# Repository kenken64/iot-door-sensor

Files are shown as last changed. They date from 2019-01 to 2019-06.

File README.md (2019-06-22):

# Door/Window Sensor - Internet of Things

## Tindie Store - Order the device here https://bit.ly/2L2vBSy 

### If you would like to see further enhancement of this whole iot platform kindly donate to my BTC account

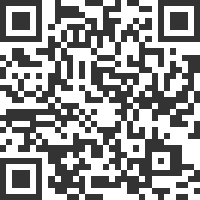
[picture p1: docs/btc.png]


IMAGE ALT TEXT HERE (https://www.youtube.com/watch?v=pYRvByaGBP0)

IMAGE ALT TEXT HERE (https://youtu.be/cuYwMgwrSvQ)

Nothing spells security than being notified or alerted if somebody has entered your premises without your permission. It also helps when even before someone can gain entry, you already know who he or she is. The main idea of this door/window sensor is to simply provide you information if someone has gone through any of your property entry points.

## Works with Many Entry Points

The door/window sensor is primarily used to detect people or objects that have passed through the doors, but it’s also compatible to windows and any enclosures that could be opened.

## Small to Notice

The door/window sensor is a very unassuming device so it blends well with the rest of the commonly found items or appliances in your home. It is also quite small you can easily hide it well, away from the prying eyes of potential intruders, and it doesn’t get in the way with the actual functions of the entry points.

The device is a magnetic switch that allows it to accurately determine location and direction. In other words, there are no false alarms and leads.

## Very Easy and Fast Installation

As a magnetic device, it doesn’t require any intricate tools to install. In fact, you simply need to snap it into any metal part of your entryway, and you can already properly and quickly configure the door sensor. If not, you can conveniently attached even a small piece of metal at any part of the door and window.

## Works on the cloud

A connected home brings devices and services together for an integrated, autonomous experience that improves a consumer’s life. Connected home experiences include everything from window/door sensor , voice-controlled lights, house-cleaning robots, machine learning-enabled security cameras, and WiFi routers that troubleshoot for you. Thanks to decreasing costs and increasing options for connectivity, these smart home devices, sensors, and tools can be interlinked to create real-time, contextual, and smart experiences for consumers.

IoT powers the connected home by bringing new features and capabilities to smart devices, like interconnectivity, security, offline communication, predictive maintenance, analytics for consumer insights, and machine learning. Each of these capabilities play a different role in key connected home use cases such as home automation, home security and monitoring, and home networking.

# Multiple version
- Wifi version
- Sigfox version
- Lorawan version require an existing lorawan gateway (Prototype, too expensive)

# Pre-requisite Lora Gateway
- Use the raspi-config tool (with sudo raspi-config) to enable SPI on the Raspberry Pi
- Install wiringpi (sudo apt-get install wiringpi)

# Pre-requisite microcontroller and parts
- Adafruit Huzzah ESP8266/TTGO ESP32 Wifi/Arduino UNO
- 2-way connector
- LED
- 47k Ohm Resistor
- 10k Ohm Resistor
- 220 Ohm Resistor
- Magnetic Door Sensor
- Jumper
- Custom made PCB by kenken64
- Lipo Battery/ 18650 battery
- Headers 
- UnaShield Sigfox for Arduino UNO

## 3D printed Casing/Housing
- ESP8266/ESP32 STL 3d Design
- Sigfox STL 3d Design

# PCB Design (Eagle and Fritzing)
- WIFI Version 1 (Custom made PCB)
<br>
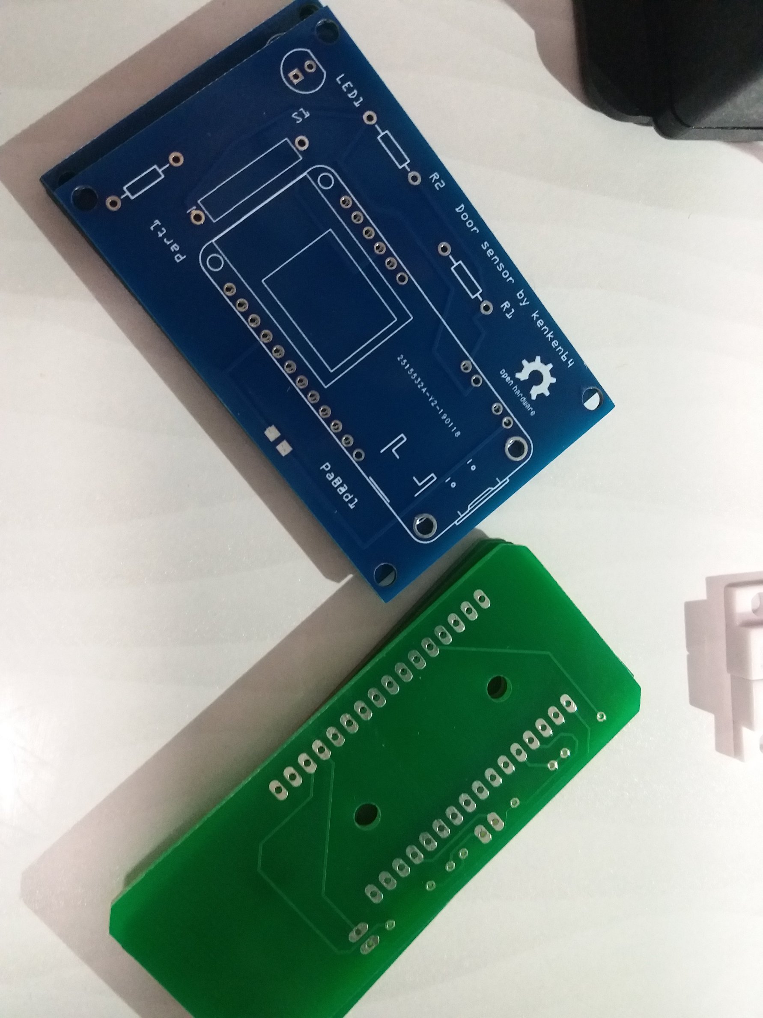
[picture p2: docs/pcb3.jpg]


- WIFI Version 2 (Custom made PCB)
<br>
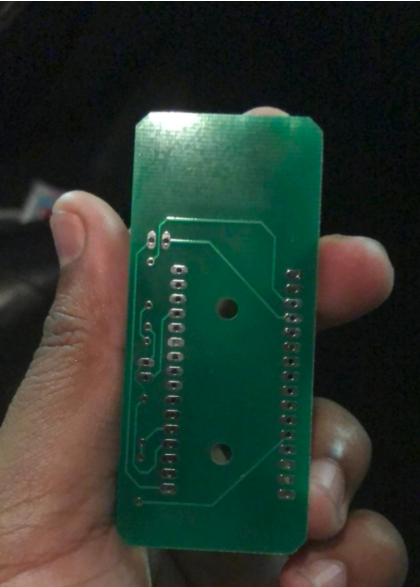
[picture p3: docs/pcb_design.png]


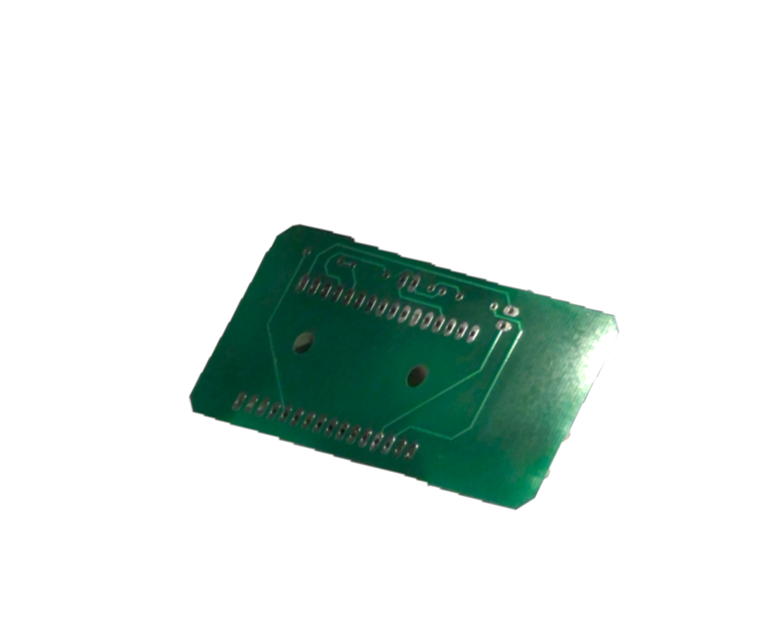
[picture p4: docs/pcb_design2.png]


- Sigfox version (Shield from UnaBiz)

# Pre-requisite software & library

- Microsoft Visual Studio Code
- Node JS
- Ubuntu/Windows 10 ( 2 CPU and 2GB ram )
- Angular 7 Cli
- Arduino IDE
- ESPBattery
- ESP 8266/32 Arduino library
- Unashield Sigfox library

# Pre-requisite Cloud account

- Twilio (require your own credit to send out SMS/WhatsApp)
- Gmail https://mail.google.com/mail/u/0/
- Google Firebase Realtime Database https://console.firebase.google.com/u/0/?pli=1
- Blynk Cloud Service ( Mobile App) 

# Twilio - SMS and WhatsApp Notification

- Create a twilio account and top up with the credits.
- Note down the twilio SSID and AUTH TOKEN.
- Purchase a number from Twilio
- Also note down the WhatsApp from number

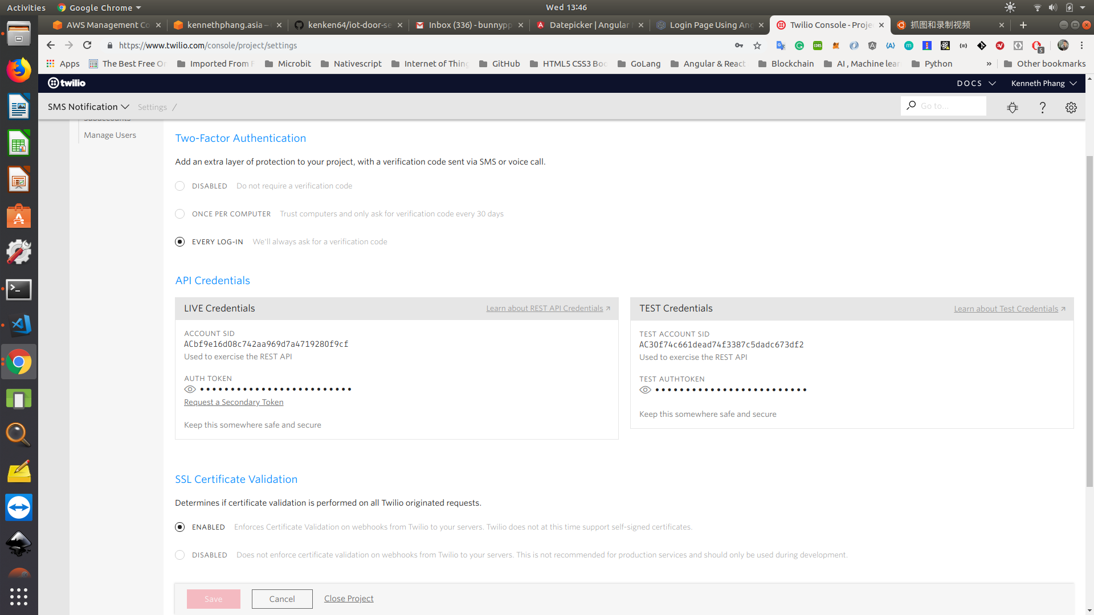
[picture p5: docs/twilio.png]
Image of Twilio


# SMTP or Gmail account Email notification

- Create gmail account. Please do not use personal gmail account for this.
- Enable unsecure access to this account [Gmail API setting](https://support.google.com/accounts/answer/6010255?hl=en)

# Backend Server Side (AWS Lightsail/ DO / Azure / Google Cloud)
- Detect door is open and closed.
- Send SMS using twilio to the configure recipient mobile number
- Send notification email to the configure recipient email address
- Detect battery is low send notification via SMS and email
- Log all events to the door's device
- Provide exportable reporting of all doors 

# Environment variable

| Env variables | Description | 
| --- |:---:|
| SMTP_GMAIL_ACC | Gmail SMTP account that use to send email to security guard  | 
| SMTP_GMAIL_PASSWORD | Password for the above email account |  
| TWILIO_SSID | SSID for the twilio sms APIs | 
| TWILIO_AUTH_TOKEN | Security token for the twilio sms APIs | 
| TWILIO_NUMBER | You need a twilio phone number in order to send SMS to the receipient | 
| FIREBASE_DB_URL | NoSQL Database url | 
| JOB_INTERVAL | Interval period where the job poll for the changes from firebase and the blynk APIs | 
| JOB_TIMEOUT | Tiemout period where the job poll for the changes from firebase and the blynk APIs | 
| NOTIFICATION_ENABLE | Disable and enable notification when door is open and closed | 
| FIREBASE_SVC_ACC_FILE | Firebase credential file to perform admin operations e.g.  https://door-sensor-proj.firebaseio.com  | 
| CLEAN_UP_SCHEDULE | Schedule timing to cleanup events logs | 
| BLYNK_API_URL | Blynk IOT API URL  e.g. http://blynk-cloud.com/ | 
| SIGFOX_SERVER_PORT | Sigfox callback backend server port number |
| TWILIO_WHATSAPP_NO | Twilio WhatsApp from number |

# Door/Window sensor Web App

## List of door/window installed with sensor

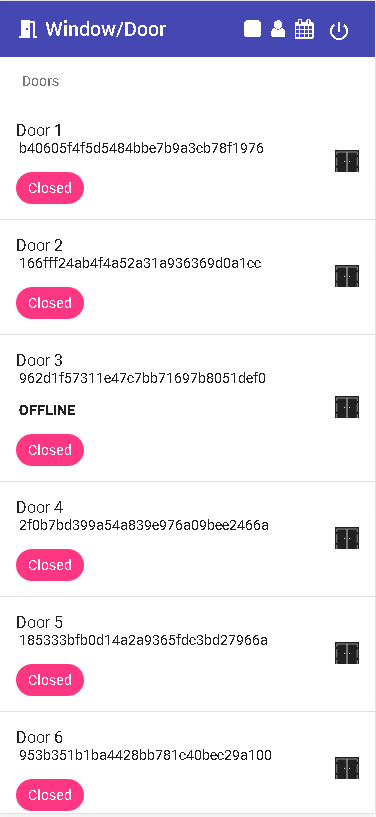
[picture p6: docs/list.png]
List of doors


## Add new door/window sensor
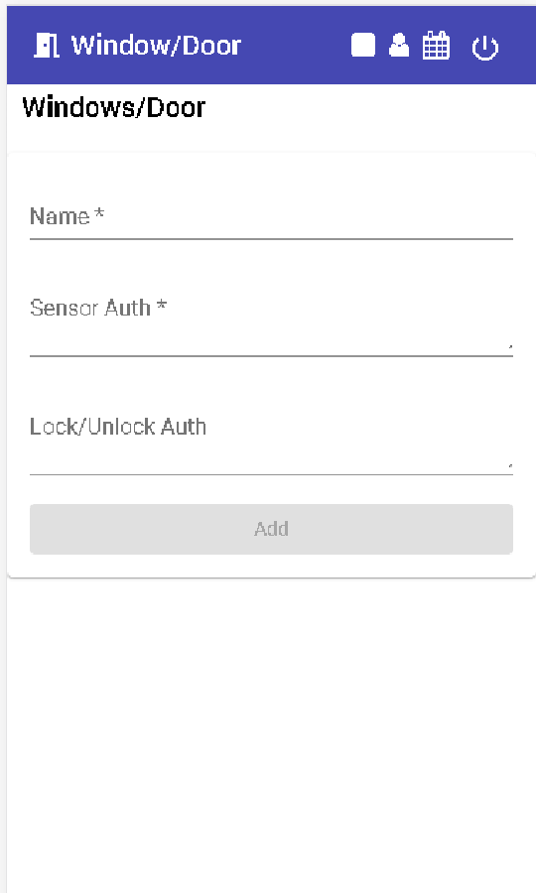
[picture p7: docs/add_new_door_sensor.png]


## Add new security personel to the system
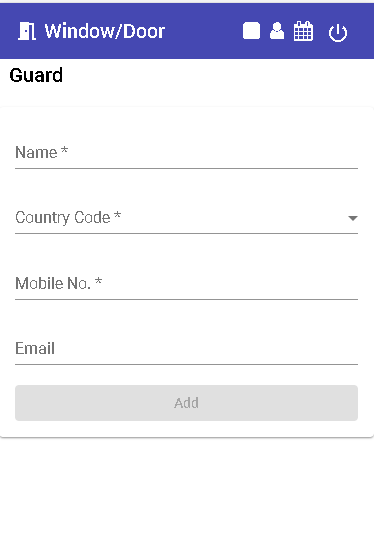
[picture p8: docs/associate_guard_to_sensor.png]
Add guard to the system


## Associate multiple security guard to the sensors
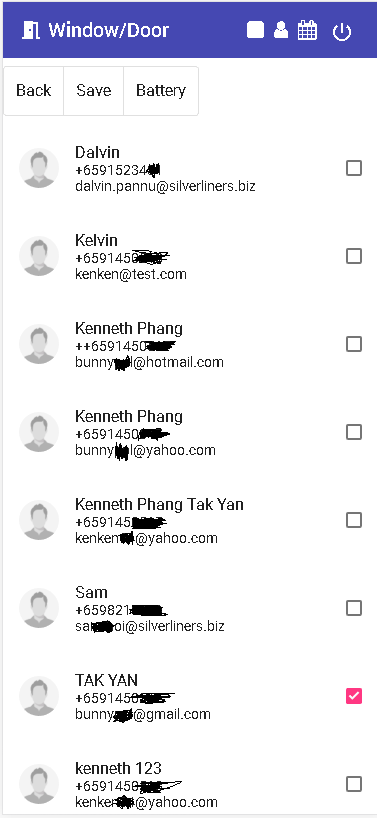
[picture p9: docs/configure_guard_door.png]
Associate guard to the door sensors


## Provide feedback on door/window events
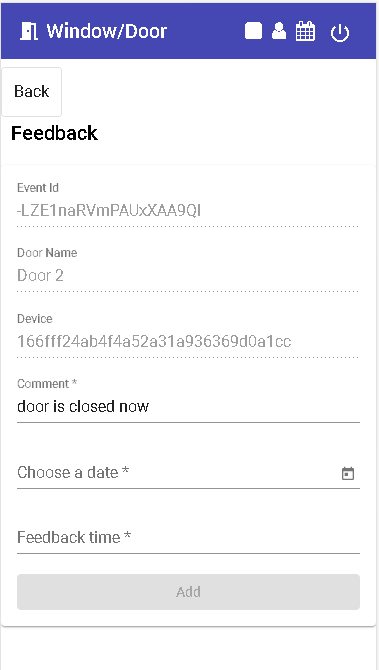
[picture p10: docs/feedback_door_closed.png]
feedback on events


## SMS Notification
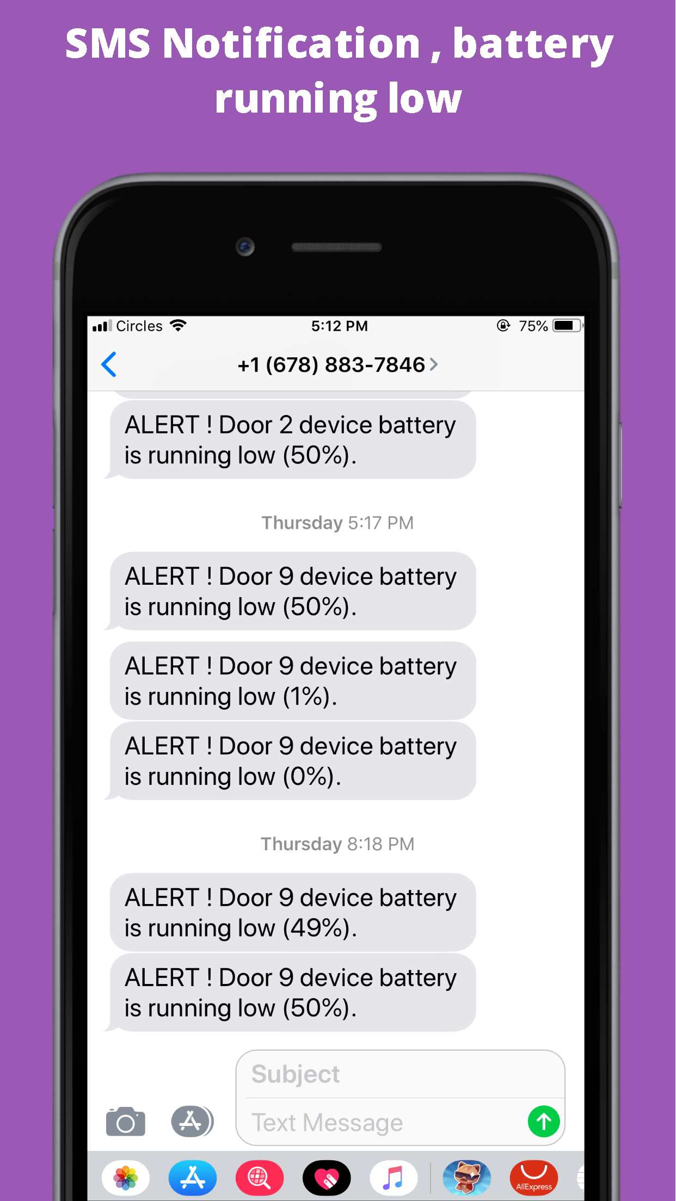
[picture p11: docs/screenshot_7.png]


## Email Notification
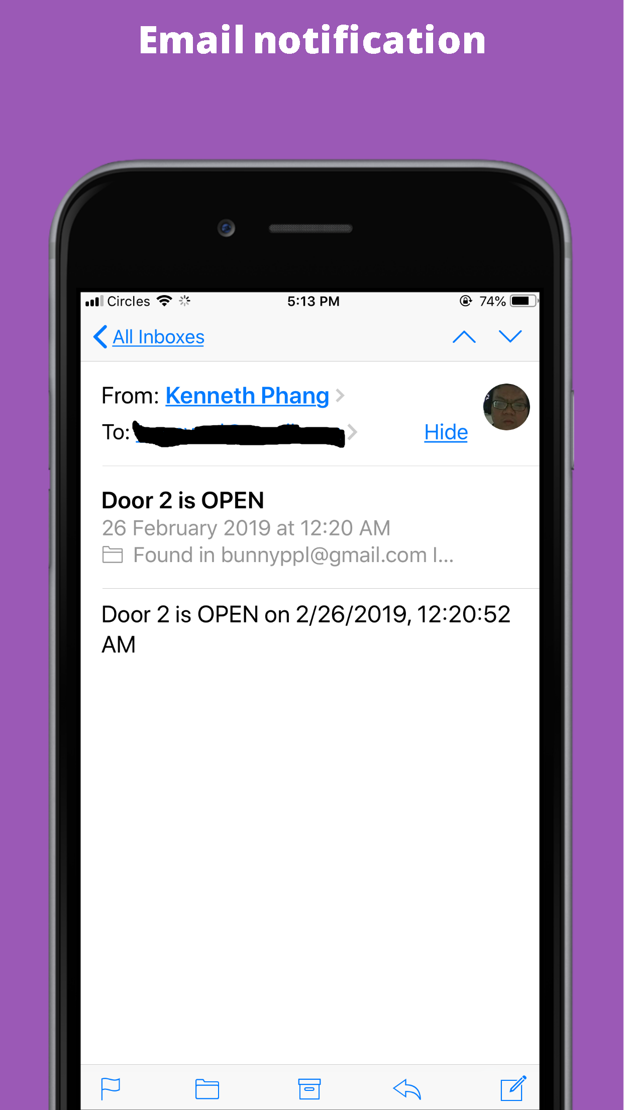
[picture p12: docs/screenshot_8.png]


## WhatsApp Notification
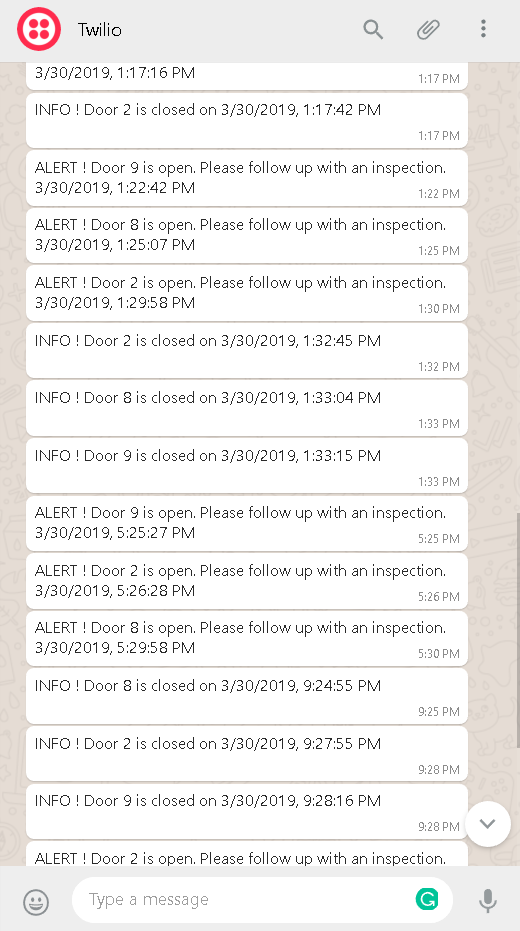
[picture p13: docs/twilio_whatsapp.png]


## Export as Excel Spreadsheet
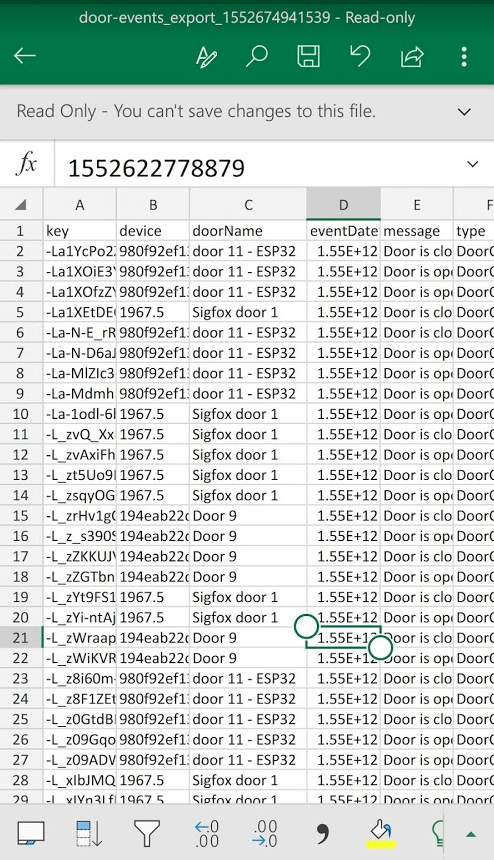
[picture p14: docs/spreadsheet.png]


# Setup Instructions for the PWA Web App and Backend

Kindly create a Azure/AWS/Google Cloud account to deploy all this component on a Ubuntu 18.04 distribution

After creating a cloud instance, ssh/login into the instance install git software and node js. Please follow the links below with all the installation steps 

https://www.digitalocean.com/community/tutorials/how-to-install-git-on-ubuntu-18-04-quickstart

https://www.digitalocean.com/community/tutorials/how-to-install-node-js-on-ubuntu-18-04

This project was generated with [Angular CLI](https://github.com/angular/angular-cli) version 7.1.4.

## Logon to the newly created cloud server and pull down the github source codes using the below linux command

```
cd ~
git clone https://github.com/kenken64/iot-door-sensor.git
```
## Development server

Run `ng serve` for a dev server. Navigate to `http://localhost:4200/`. The app will automatically reload if you change any of the source files.

## Code scaffolding

Run `ng generate component component-name` to generate a new component. You can also use `ng generate directive|pipe|service|class|guard|interface|enum|module`.

## Build

Run `ng build` to build the project. The build artifacts will be stored in the `dist/` directory. Use the `--prod` flag for a production build.

## Running unit tests

Run `ng test` to execute the unit tests via [Karma](https://karma-runner.github.io).

## Running end-to-end tests

Run `ng e2e` to execute the end-to-end tests via [Protractor](http://www.protractortest.org/).

## Further help

To get more help on the Angular CLI use `ng help` or go check out the [Angular CLI README](https://github.com/angular/angular-cli/blob/master/README.md).

## Install PWA from dist directory to Nginx 

Use the link below for the nginx installation

https://www.digitalocean.com/community/tutorials/how-to-install-nginx-on-ubuntu-18-04

Right after the web server is installed, install free SSL certificate using Let's Encrypt 

https://www.digitalocean.com/community/tutorials/how-to-secure-nginx-with-let-s-encrypt-on-ubuntu-18-04

Lastly, copy all the files from the angular app /dist directory to the nginx web server root directory e.g. /var/www/html

## Google Firebase

It is must to have Google account in order to create a firebase account for this project

1. Create a firebase real time database project following this link https://firebase.google.com/

## Install and start redis server

1. Install redis server

```
sudo apt-get update
sudo apt-get install redis
```

2. Start Redis server

```
sudo service redis-server start
```
3. Check redis server status
```
sudo service redis-server status
```

4. if only there is a crash on the worker process then run flush

```
redis-cli FLUSHALL
```

## Start Backend server
How to start the sms and email backend server that poll the devices.

```
$ cd server/
$ npm i 
$ pm2 start server.js --name server --max-memory-restart 1G --restart-delay 10000 --node-args="--expose-gc --max-old-space-size=4096"
```

## Start Door Sensor Worker Engine to poll door's state
Worker consumes the job from the delegator to check the door sensors and send out notification via SMS/WhatsApp/Email.

Each worker is configured with its own designated door sensor's blynk auth key. Refer to the server/worker-config.json

```
[
    {
        "workerName": "worker1",
        "doors": ["b40605f4f5d5484bbe7b9a3cb78f1376",
                "962d1f57311e47c7bb71697b8051de30",
                "980f92ef13db430594a89315d86dd37b"

        ]
    },
    {
        "workerName": "worker2",
        "doors": [ "185333bfb0d14a2a9365fdc3bd37966a",
                "953b351b1ba4428bb781c40bec29a300",
                "194eab22d2bd49c0a580c01d7d19ce34"
        ]
    },
    {
        "workerName": "worker3",
        "doors": [ "166fff24ab4f4a52a31a936369d3a1cc",
                "2dde80b00cf342c1b6977e91dd9b6039"
        ]
    },
    {
        "workerName": "worker4",
        "doors": [ "c56c9a1ab4b1415998c06173786354f2",
                "2f0b7bd399a54a839e976a09bee2463a"
        ]
    }
]
```

```
$ cd server/
$ pm2 start worker.js --name worker --max-memory-restart 500M -- --workername=worker1 --node-args="--expose-gc
$ pm2 start worker.js --name worker2 --max-memory-restart 500M -- --workername=worker2 --node-args="--expose-gc
$ pm2 start worker.js --name worker3 --max-memory-restart 500M -- --workername=worker3 --node-args="--expose-gc
$ pm2 start worker.js --name worker4 --max-memory-restart 500M -- --workername=worker4 --node-args="--expose-gc
```

## Blynk Configuration

Go to your Google App Store/Apple store search for Blynk, install it

Register an account with Blynk

Create a new project, choose device as ESP8266 WIFI send the auth key to your email address

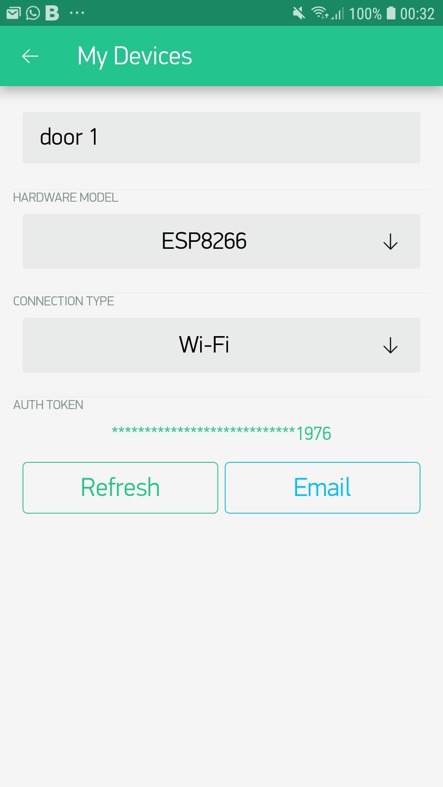
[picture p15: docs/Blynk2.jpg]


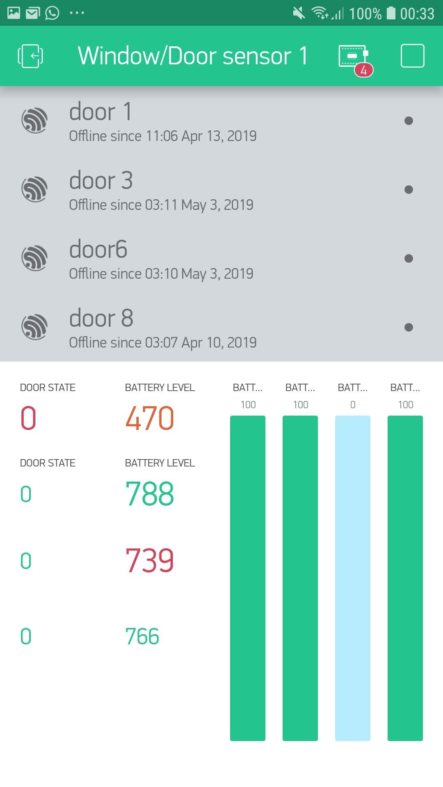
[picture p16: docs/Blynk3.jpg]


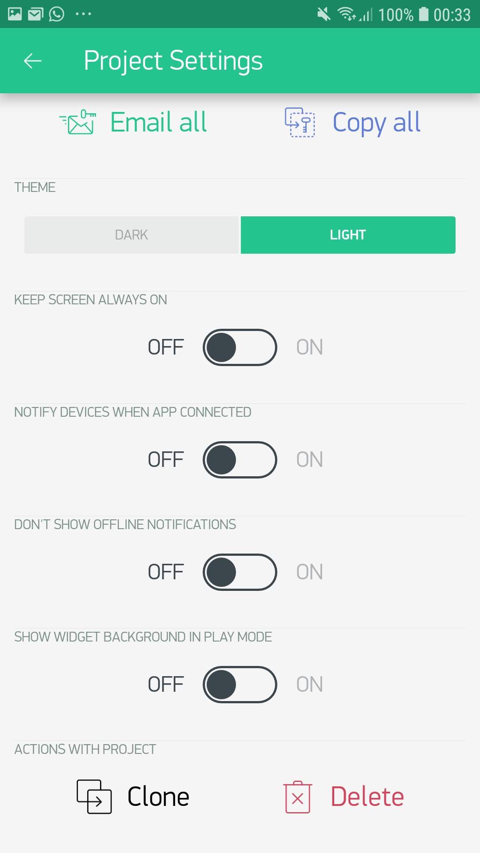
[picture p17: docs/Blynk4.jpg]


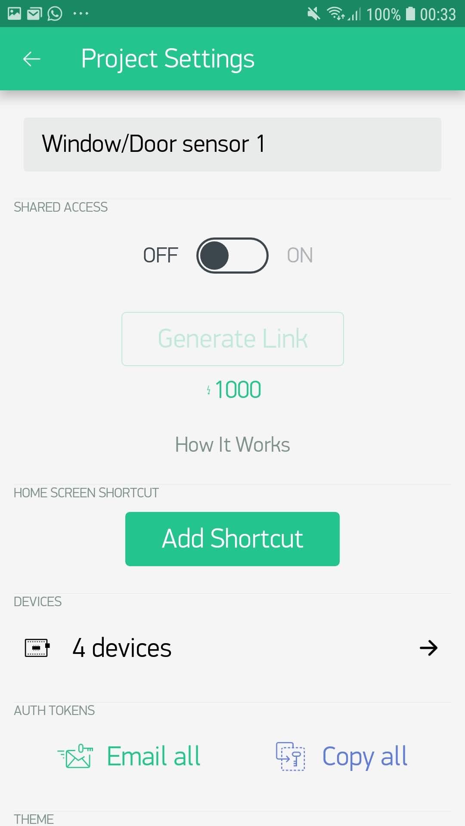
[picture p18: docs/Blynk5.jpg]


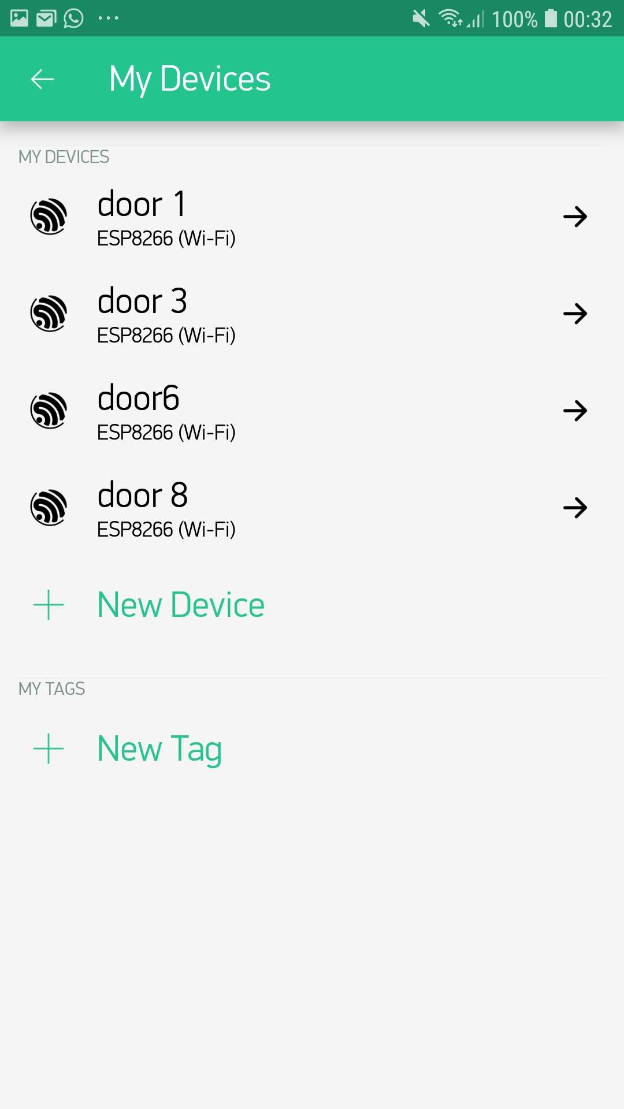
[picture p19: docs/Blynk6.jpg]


## Restful API for Blynk

Below is the link to test out the API using your REST client
https://blynkapi.docs.apiary.io/#

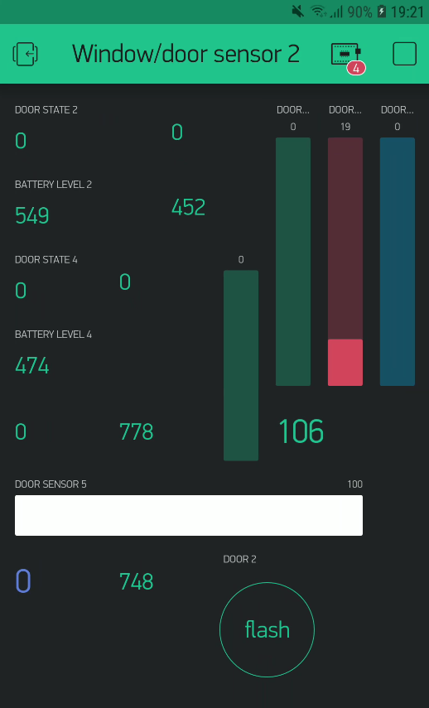
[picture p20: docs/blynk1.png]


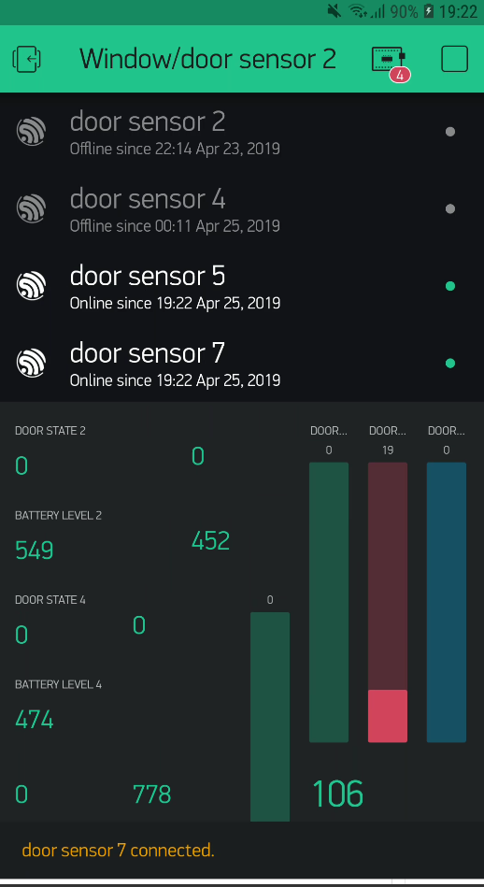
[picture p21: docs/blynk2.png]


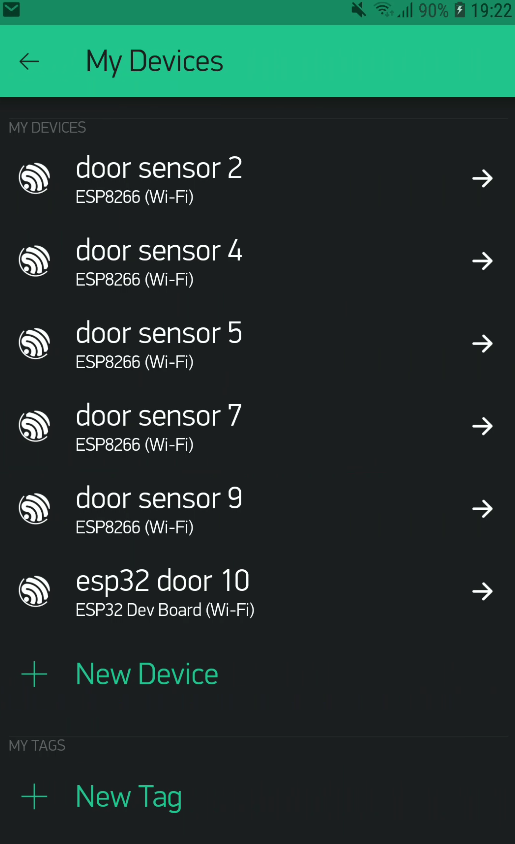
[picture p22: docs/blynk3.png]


## Install firmware to the ESP8266/ESP32

1. Plug the ESP8266 to your computer
2. Launch Arduino IDE , open up the Arduino sketch from the directory /firmware/door_sensor/door_sensor.ino
3. Search for the codes, replace the double quote values according to the auth code from the blynk email from your mailbox
```
char blynk_token[33] = "166fff24ab4f4a52a31a936369d0a1cc";
```
4. Make sure ESP8266 board are installed using the board manager.

arduino board

5. Select the configuration properly before compiling and flashing the ESP8266. Take note the flash size and port.

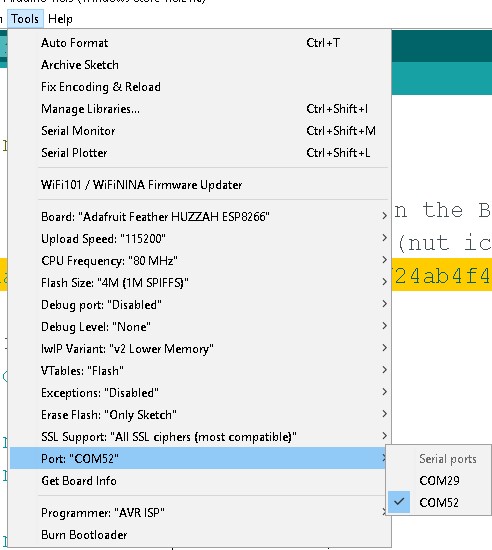
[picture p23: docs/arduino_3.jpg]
config


5. The following libraries is amust to be installed before sync the firmware to the ESP8266 board
  - ArduinoJson (Take note do not use the latest version)
  arduino Json

  - FS
  SPI Flash
  unified sensor

  - ESPBattery (https://github.com/LennartHennigs/ESPBattery)
  - Blynk
  blynk

  - WifiManager
  wifimanager  

6. Compile and sync the firmware to the microcontroller board

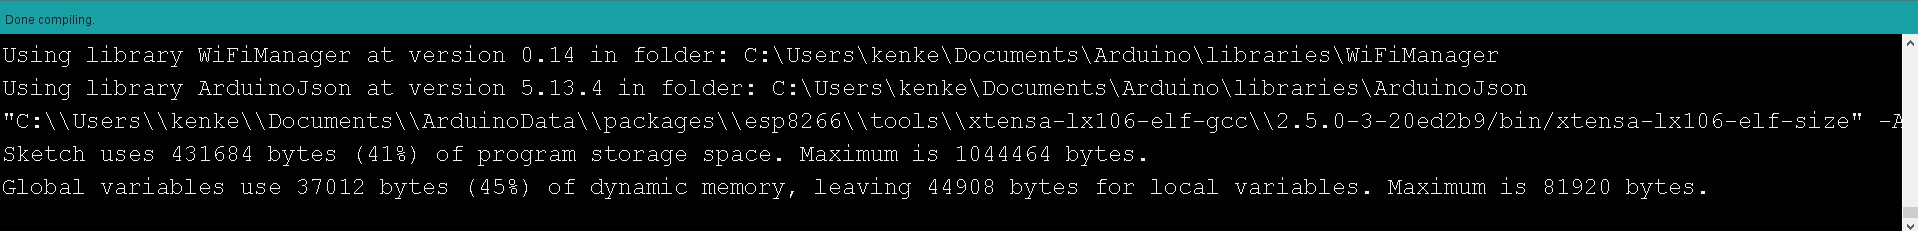
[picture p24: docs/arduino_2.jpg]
compile sync


## Once everything is setup and up running on the cloud

Last thing to do is to power up the door sensor using a micro usb cable, at first if there isn't any wifi setting being configure. the device  will act as an wireless access point with the SSID stated as "AutoAPDoorSensor" Access the portal via the following web address htttp://192.168.244.1

Configure the door sensor device to connect to your own wifi router with credential. Do not change the blynk auth key.

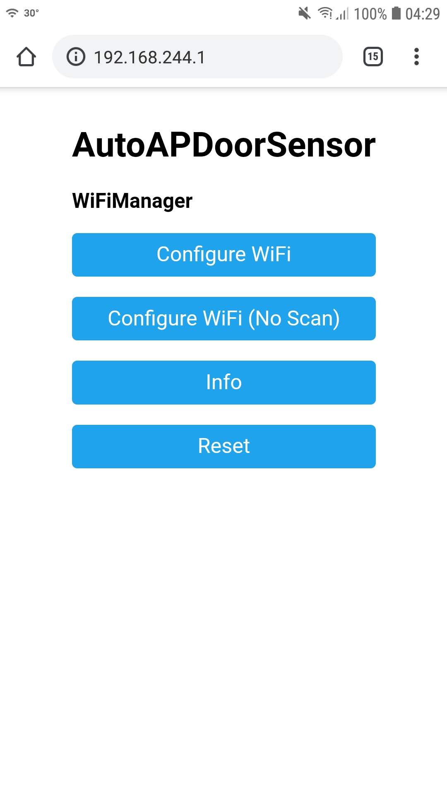
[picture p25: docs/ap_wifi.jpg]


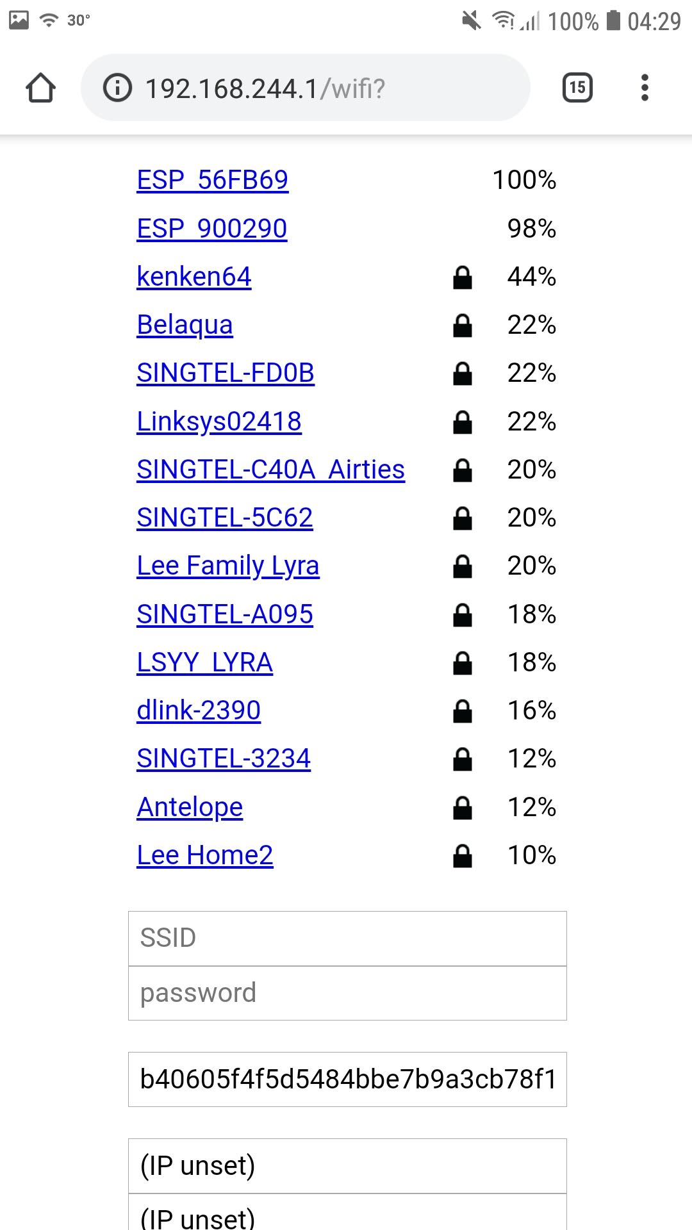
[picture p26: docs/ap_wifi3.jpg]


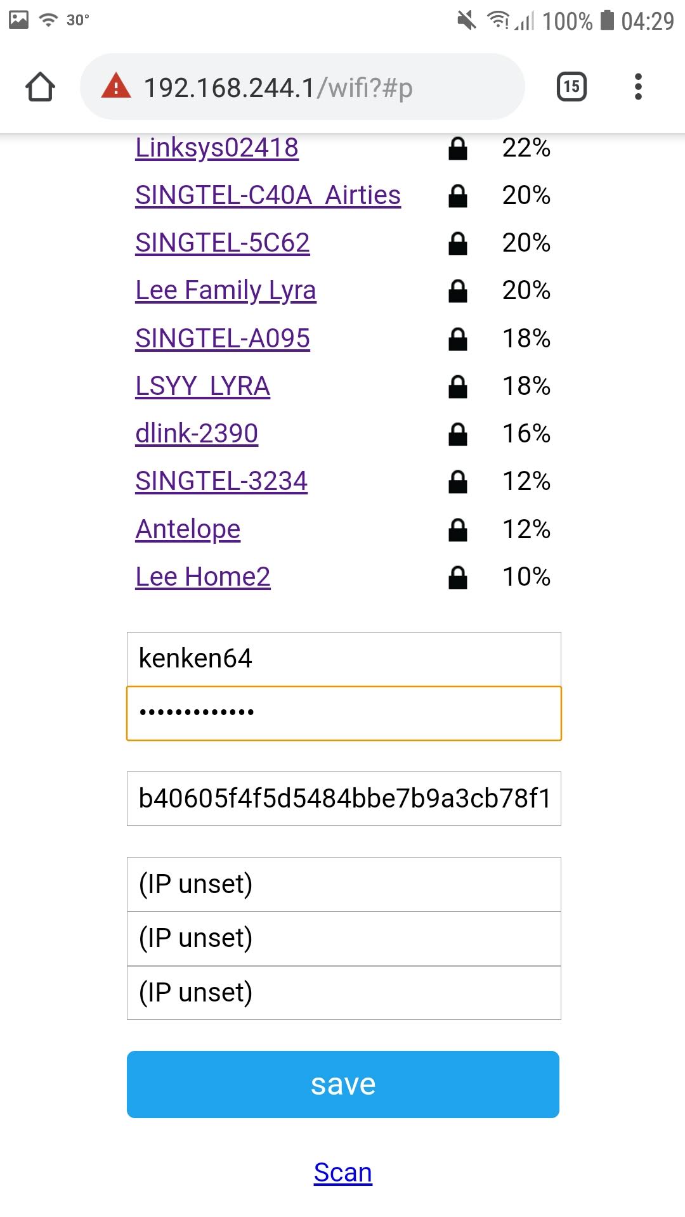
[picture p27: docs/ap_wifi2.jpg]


## Check the health of all processes
```
pm2 list
```
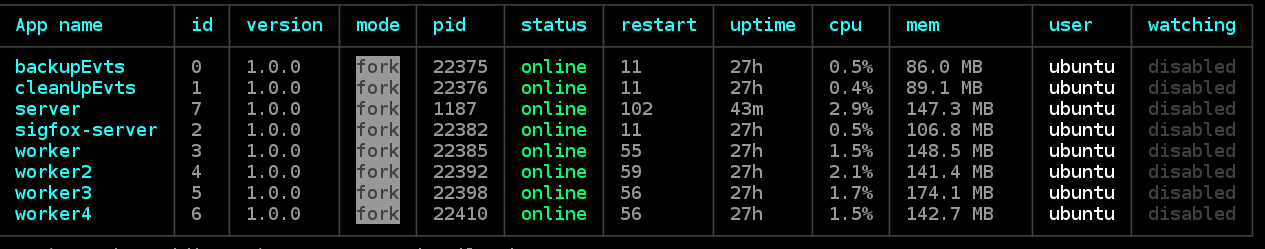
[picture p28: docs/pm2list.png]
pm2 list


## Debug memory leakage
- Use ChromeDev Tools
- Dynatrace (https://www.dynatrace.com/)
- Sentry io (https://sentry.io/welcome/)

## Future work - Integrate with ElectricMagnetic lock 

Most of the EM lock in the market uses 12v AC likely need to enhance the PCB board

https://shopee.sg/Hot-DC-DC-Converter-Output-Power-Adapter-24V-12V-To-5V-USB-Step-Down-Module-i.10885840.691201434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

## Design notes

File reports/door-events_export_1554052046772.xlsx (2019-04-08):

key | device | doorName | eventDatetime | message | type | feedbackcnt
-LbJhYLAxj5AkwDbXFJq | 980f92ef13db430594a89315d86dd77b | door 11 - ESP32 | 1554051904958 | Door is open | DoorOpen
-LbG9qbOESUnvReJJRC1 | 166fff24ab4f4a52a31a936369d0a1cc | Door 2 | 1553992477195 | Door is closed | DoorClosed
-LbG9p6t_31eekwN8Nhz | 166fff24ab4f4a52a31a936369d0a1cc | Door 2 | 1553992471083 | Door is open | DoorOpen
-LbF4HRLtCv06RyEZqPL | 980f92ef13db430594a89315d86dd77b | door 11 - ESP32 | 1553974241097 | Door is closed | DoorClosed
-LbF4BapXU5PSPsuM1WS | 980f92ef13db430594a89315d86dd77b | door 11 - ESP32 | 1553974217192 | Door is open | DoorOpen
-LbF23VppiVC7AHFCAK1 | 980f92ef13db430594a89315d86dd77b | door 11 - ESP32 | 1553973659752 | Door is closed | DoorClosed
-LbF1b_nuyKv48idWVYl | 980f92ef13db430594a89315d86dd77b | door 11 - ESP32 | 1553973541286 | Door is open | DoorOpen
-LbEzBxsZmUcK-HE3RZI | 980f92ef13db430594a89315d86dd77b | door 11 - ESP32 | 1553972645803 | Door is closed | DoorClosed
-LbEyXHlW8qjmYxzAT_T | 980f92ef13db430594a89315d86dd77b | door 11 - ESP32 | 1553972471012 | Door is open | DoorOpen
-LbEYIYzXVmZFBGb-Gbn | 166fff24ab4f4a52a31a936369d0a1cc | Door 2 | 1553965332785 | Door is closed | DoorClosed
-LbEYH3oPG80vjXWrKoD | 166fff24ab4f4a52a31a936369d0a1cc | Door 2 | 1553965326694 | Door is open | DoorOpen
-LbE0enKn01YblO7EN7C | 166fff24ab4f4a52a31a936369d0a1cc | Door 2 | 1553956515079 | Door is closed | DoorClosed
-LbE09NuWr0WJ_i1VxAT | 166fff24ab4f4a52a31a936369d0a1cc | Door 2 | 1553956382316 | Door is open | DoorOpen
-LbDvbwL5F5xs5sZkF97 | 166fff24ab4f4a52a31a936369d0a1cc | Door 2 | 1553954934039 | Door is closed | DoorClosed
-LbDvEdwf5Irp-qYl86a | 166fff24ab4f4a52a31a936369d0a1cc | Door 2 | 1553954834557 | Door is open | DoorOpen
-LbDmJpFzunIPoxMLrfH | 194eab22d2bd49c0a580c01d7d19ce44 | Door 9 | 1553952496420 | Door is closed | DoorClosed
-LbDmEh007m0BIL5UEbW | 166fff24ab4f4a52a31a936369d0a1cc | Door 2 | 1553952475412 | Door is closed | DoorClosed
-LbDlYqbU7AalJLbQc5t | c56c9a1ab4b1415998c06173786454f2 | Door 8 | 1553952295506 | Door is closed | DoorClosed
-LbCvm6ujX3tMpaGg5Z9 | c56c9a1ab4b1415998c06173786454f2 | Door 8 | 1553938198181 | Door is open | DoorOpen
-LbCuynzfubFud5L3ltw | 166fff24ab4f4a52a31a936369d0a1cc | Door 2 | 1553937988012 | Door is open | DoorOpen
-LbCujvWsiUAAoS5gcs- | 194eab22d2bd49c0a580c01d7d19ce44 | Door 9 | 1553937927060 | Door is open | DoorOpen
-LbC4aiUu0B3rXRMKoM2 | 194eab22d2bd49c0a580c01d7d19ce44 | Door 9 | 1553923995449 | Door is closed | DoorClosed
-LbC4Z3IujFd2DL-WBQU | c56c9a1ab4b1415998c06173786454f2 | Door 8 | 1553923984554 | Door is closed | DoorClosed
-LbC4UOF-QtK1Jrwupyu | 166fff24ab4f4a52a31a936369d0a1cc | Door 2 | 1553923965417 | Door is closed | DoorClosed
-LbC3qTX1ZaQKLYrBip8 | 166fff24ab4f4a52a31a936369d0a1cc | Door 2 | 1553923797819 | Door is open | DoorOpen
-LbC2jSPwQlkLe3CMb9D | c56c9a1ab4b1415998c06173786454f2 | Door 8 | 1553923506903 | Door is open | DoorOpen
-LbC2B6hIbkSxb11lPas | 194eab22d2bd49c0a580c01d7d19ce44 | Door 9 | 1553923362158 | Door is open | DoorOpen
-LbC11kzToeCQnQw2DZF | 166fff24ab4f4a52a31a936369d0a1cc | Door 2 | 1553923061692 | Door is closed | DoorClosed
-LbC0wTUq6ODVgqIYA8s | 166fff24ab4f4a52a31a936369d0a1cc | Door 2 | 1553923035932 | Door is open | DoorOpen
-LbBzAV1fcKUq9rwFM6O | 166fff24ab4f4a52a31a936369d0a1cc | Door 2 | 1553922311037 | Door is closed | DoorClosed
-LbByqNt5y6tALvIQPkJ | 166fff24ab4f4a52a31a936369d0a1cc | Door 2 | 1553922224563 | Door is open | DoorOpen
-LbBtDIWIDM1xUbAMDD7 | 166fff24ab4f4a52a31a936369d0a1cc | Door 2 | 1553920749635 | Door is closed | DoorClosed
-LbBtArpjILaWVlY_XfR | 166fff24ab4f4a52a31a936369d0a1cc | Door 2 | 1553920739671 | Door is open | DoorOpen
-LbBsxxXh0H3BcSDuWva | 166fff24ab4f4a52a31a936369d0a1cc | Door 2 | 1553920682691 | Door is open | DoorOpen
-LbBrqf8_DRZe51GHhWX | 166fff24ab4f4a52a31a936369d0a1cc | Door 2 | 1553920390687 | Door is closed | DoorClosed
-LbBegRynJfydQi0RYww | 166fff24ab4f4a52a31a936369d0a1cc | Door 2 | 1553916940864 | Door is open | DoorOpen
-Lb9k7stFvZPYi2gk4Pf | 166fff24ab4f4a52a31a936369d0a1cc | Door 2 | 1553884812999 | Door is closed | DoorClosed
-Lb9k1c3uTLVlwtuJR8N | 166fff24ab4f4a52a31a936369d0a1cc | Door 2 | 1553884787345 | Door is open | DoorOpen
-Lb9j6nhOxlyQLvP2czE | 166fff24ab4f4a52a31a936369d0a1cc | Door 2 | 1553884546426 | Door is closed | DoorClosed
-Lb9hn9R4HJCV5dAaVVz | 166fff24ab4f4a52a31a936369d0a1cc | Door 2 | 1553884199707 | Door is open | DoorOpen
-Lb9edZbjP7qyD6bmQh0 | c56c9a1ab4b1415998c06173786454f2 | Door 8 | 1553883373976 | Door is closed | DoorClosed
-Lb9eY9HkcYBfAvVf3zs | 166fff24ab4f4a52a31a936369d0a1cc | Door 2 | 1553883347715 | Door is closed | DoorClosed
-Lb9eMJlBwC80lkaq-zD | c56c9a1ab4b1415998c06173786454f2 | Door 8 | 1553883299234 | Door is open | DoorOpen
-Lb9eIQ76gKDyR0SeKzT | 166fff24ab4f4a52a31a936369d0a1cc | Door 2 | 1553883283257 | Door is open | DoorOpen
-Lb9dp20wL56oBHWFrNz | c56c9a1ab4b1415998c06173786454f2 | Door 8 | 1553883158829 | Door is closed | DoorClosed
-Lb9dmh4nlIv8YqJVWht | 166fff24ab4f4a52a31a936369d0a1cc | Door 2 | 1553883149233 | Door is closed | DoorClosed
-Lb9d_Nr9EYzGYrdl9br | c56c9a1ab4b1415998c06173786454f2 | Door 8 | 1553883094691 | Door is open | DoorOpen
-Lb9dWLVsx4SWk-F23mn | 166fff24ab4f4a52a31a936369d0a1cc | Door 2 | 1553883078156 | Door is open | DoorOpen
-Lb9cFwzByTY4B0ZGAHY | c56c9a1ab4b1415998c06173786454f2 | Door 8 | 1553882748835 | Door is closed | DoorClosed
-Lb9c9VB86PR5dCSGYc4 | c56c9a1ab4b1415998c06173786454f2 | Door 8 | 1553882722415 | Door is open | DoorOpen
-Lb9c4c2KMrISi6HIs_q | c56c9a1ab4b1415998c06173786454f2 | Door 8 | 1553882702438 | Door is closed | DoorClosed
-Lb9c4KUGgBpqNgY1JDO | 166fff24ab4f4a52a31a936369d0a1cc | Door 2 | 1553882701251 | Door is closed | DoorClosed
-Lb9bZ4yb63dhlHDQgF_ | c56c9a1ab4b1415998c06173786454f2 | Door 8 | 1553882565086 | Door is open | DoorOpen
-Lb9bWJUX8R_CxoQRujq | 166fff24ab4f4a52a31a936369d0a1cc | Door 2 | 1553882553727 | Door is open | DoorOpen
-Lb9aKTpNrMY7oEfL8mn | c56c9a1ab4b1415998c06173786454f2 | Door 8 | 1553882243087 | Door is closed | DoorClosed
-Lb9_kXTOi8WEEcKdIIR | c56c9a1ab4b1415998c06173786454f2 | Door 8 | 1553882091773 | Door is open | DoorOpen
-Lb9XzEwL5kBM-QHX5dT | 166fff24ab4f4a52a31a936369d0a1cc | Door 2 | 1553881365573 | Door is closed | DoorClosed
-Lb9Xq1dkC67nP3ZX9TD | 166fff24ab4f4a52a31a936369d0a1cc | Door 2 | 1553881327858 | Door is open | DoorOpen
-Lb9WKILswfy7ph2xQLP | 166fff24ab4f4a52a31a936369d0a1cc | Door 2 | 1553880931607 | Door is closed | DoorClosed
-Lb9Vp_LVu_RtAfHo_MM | 166fff24ab4f4a52a31a936369d0a1cc | Door 2 | 1553880801964 | Door is open | DoorOpen
-Lb9VHnULOgpuwUPKrjB | 166fff24ab4f4a52a31a936369d0a1cc | Door 2 | 1553880659244 | Door is closed | DoorClosed
-Lb9UuPPfcNu0MyD9Fa_ | 166fff24ab4f4a52a31a936369d0a1cc | Door 2 | 1553880559319 | Door is open | DoorOpen
-Lb9OlzndxVePP1G6TY7 | 166fff24ab4f4a52a31a936369d0a1cc | Door 2 | 1553878951951 | Door is closed | DoorClosed
-Lb9I15cs4OWYWzil9Ec | 166fff24ab4f4a52a31a936369d0a1cc | Door 2 | 1553877182888 | Door is open | DoorOpen
-Lb9I15ZsRvIaMkJnIna | 166fff24ab4f4a52a31a936369d0a1cc | Door 2 | 1553877182884 | Door is open | DoorOpen
-Lb9H0-qDpUTXW-k-bSs | 166fff24ab4f4a52a31a936369d0a1cc | Door 2 | 1553876916266 | Door is closed | DoorClosed
-Lb9GgThvB1oVfIahWjm | 166fff24ab4f4a52a31a936369d0a1cc | Door 2 | 1553876832157 | Door is open | DoorOpen
-Lay54Rq1x73YLK-bSiW | 953b351b1ba4428bb781c40bec29a100 | Door 6 | 1553672460152 | Door is closed | DoorClosed
-Lay4Q-R8eS1epkOLiSW | 953b351b1ba4428bb781c40bec29a100 | Door 6 | 1553672286333 | Door is closed | DoorClosed
-Lay47r40gYsT7j6FkJf | 953b351b1ba4428bb781c40bec29a100 | Door 6 | 1553672212006 | Door is open | DoorOpen
-Lay47qrI2hZGezI4ckv | 953b351b1ba4428bb781c40bec29a100 | Door 6 | 1553672211989 | Door is open | DoorOpen
-Lay2zelEPP4D-SIDe6N | 953b351b1ba4428bb781c40bec29a100 | Door 6 | 1553671912250 | Door is open | DoorOpen
-Lay2zekC9S8icB6cr0d | 953b351b1ba4428bb781c40bec29a100 | Door 6 | 1553671912249 | Door is open | DoorOpen
-Lay-Bk3GkinYDR419MJ | 185333bfb0d14a2a9365fdc3bd27966a | Door 5 | 1553670917261 | Door is open | DoorOpen
-Lay-A1ICFocFYaWhpyj | 2dde80b00cf342c1b6977e91dd9b6009 | Door 7 | 1553670910250 | Door is open | DoorOpen
-Lay-A1GdoKENKecMxiB | 2dde80b00cf342c1b6977e91dd9b6009 | Door 7 | 1553670910248 | Door is open | DoorOpen
-Lay-2ClCTQ7Lbc7NK2y | 953b351b1ba4428bb781c40bec29a100 | Door 6 | 1553670878202 | Door is closed | DoorClosed
-Lay-2CgcgHgWYs2cPVq | 953b351b1ba4428bb781c40bec29a100 | Door 6 | 1553670878193 | Door is closed | DoorClosed
-LaxzwSJZiwWRZ18pNPr | 2dde80b00cf342c1b6977e91dd9b6009 | Door 7 | 1553670850539 | Door is closed | DoorClosed
-LaxzwS60PNph5lA1vC7 | 2dde80b00cf342c1b6977e91dd9b6009 | Door 7 | 1553670850526 | Door is closed | DoorClosed
-LaxzrkAC7EYPVjGGuaY | 2dde80b00cf342c1b6977e91dd9b6009 | Door 7 | 1553670831266 | Door is open | DoorOpen
-LaxzdPSNAhK5n2Y0E2G | 953b351b1ba4428bb781c40bec29a100 | Door 6 | 1553670772511 | Door is open | DoorOpen
-LaxzdPHvuyX708WZSsV | 953b351b1ba4428bb781c40bec29a100 | Door 6 | 1553670772507 | Door is open | DoorOpen
-LaxyhpAvGlPPCxGq7Sq | 953b351b1ba4428bb781c40bec29a100 | Door 6 | 1553670528468 | Door is closed | DoorClosed
-LaxyeBs1b3CF23d3DbA | 953b351b1ba4428bb781c40bec29a100 | Door 6 | 1553670513601 | Door is open | DoorOpen
-LaxyXF0f5_gV6viuUX6 | 953b351b1ba4428bb781c40bec29a100 | Door 6 | 1553670481034 | Door is closed | DoorClosed
-LaxuEB9UxuotlbBK2is | 953b351b1ba4428bb781c40bec29a100 | Door 6 | 1553669354405 | Door is open | DoorOpen
-LaxspNKe1FgusGW2CPy | 953b351b1ba4428bb781c40bec29a100 | Door 6 | 1553668986529 | Door is open | DoorOpen
-Laxr_WwYEhZcgbvdJok | 953b351b1ba4428bb781c40bec29a100 | Door 6 | 1553668659482 | Door is closed | DoorClosed
-LaxrBzTUhUkocv_M6IL | 953b351b1ba4428bb781c40bec29a100 | Door 6 | 1553668558949 | Door is closed | DoorClosed
-LaxrBzJv8Qd3B5pTcxO | 953b351b1ba4428bb781c40bec29a100 | Door 6 | 1553668558939 | Door is closed | DoorClosed
-LaxrBvmTED5A7CvQMZl | 953b351b1ba4428bb781c40bec29a100 | Door 6 | 1553668558713 | Door is closed | DoorClosed
-LaxrBuGf9TtTIShYb1u | 953b351b1ba4428bb781c40bec29a100 | Door 6 | 1553668558616 | Door is closed | DoorClosed
-LaxrBsNiDUBlHrMIhWw | 953b351b1ba4428bb781c40bec29a100 | Door 6 | 1553668558494 | Door is closed | DoorClosed
-LaxrBqlkizsmBB-ISbN | 953b351b1ba4428bb781c40bec29a100 | Door 6 | 1553668558391 | Door is closed | DoorClosed
-LaxrBoTrmQOM-u1W_Ci | 953b351b1ba4428bb781c40bec29a100 | Door 6 | 1553668558245 | Door is closed | DoorClosed
-LaxrBoPj9IpTHJY_ZCF | 953b351b1ba4428bb781c40bec29a100 | Door 6 | 1553668558241 | Door is closed | DoorClosed
-LaxrBl3ypGgdBF9tYYE | 953b351b1ba4428bb781c40bec29a100 | Door 6 | 1553668558027 | Door is closed | DoorClosed
-LaxrBkkO92k5jK7Lbam | 953b351b1ba4428bb781c40bec29a100 | Door 6 | 1553668558006 | Door is closed | DoorClosed
-LaxrBhJSEuXegM2We7f | 953b351b1ba4428bb781c40bec29a100 | Door 6 | 1553668557787 | Door is closed | DoorClosed
-LaxrBh3Nf5OkuOVzZMi | 953b351b1ba4428bb781c40bec29a100 | Door 6 | 1553668557771 | Door is closed | DoorClosed
-LaxrBd059LE4N7A6qpj | 953b351b1ba4428bb781c40bec29a100 | Door 6 | 1553668557512 | Door is closed | DoorClosed
-LaxrB_tZCTYEn8FdWUf | 953b351b1ba4428bb781c40bec29a100 | Door 6 | 1553668557312 | Door is closed | DoorClosed
-LaxrBZzdJX--AuRIqiK | 953b351b1ba4428bb781c40bec29a100 | Door 6 | 1553668557254 | Door is closed | DoorClosed
-LaxrBZYpXzPAhRDhsI8 | 953b351b1ba4428bb781c40bec29a100 | Door 6 | 1553668557226 | Door is closed | DoorClosed
-LaxrBW5uAPeWt0IRr3- | 953b351b1ba4428bb781c40bec29a100 | Door 6 | 1553668557005 | Door is closed | DoorClosed
-LaxrBVUicLht6Aj8zka | 953b351b1ba4428bb781c40bec29a100 | Door 6 | 1553668556966 | Door is closed | DoorClosed
-LaxrBR0-XzCtFoqmtyn | 953b351b1ba4428bb781c40bec29a100 | Door 6 | 1553668556680 | Door is closed | DoorClosed
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

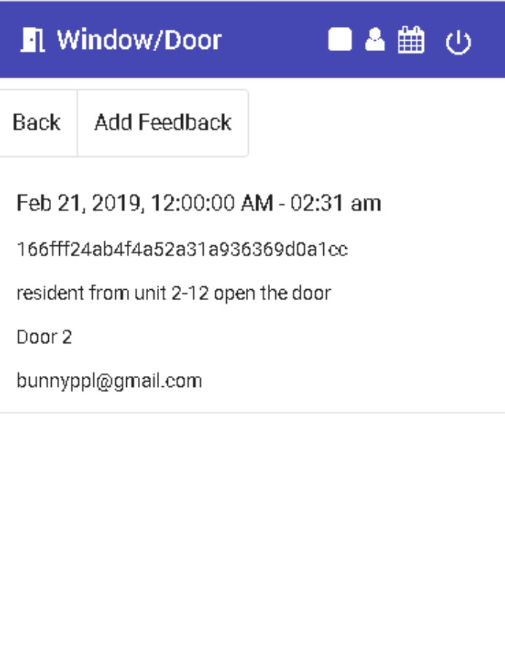
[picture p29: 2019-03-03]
docs/tindie/list_of_feedback.jpg

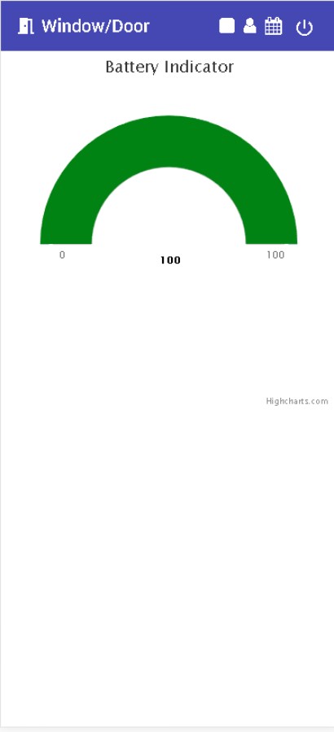
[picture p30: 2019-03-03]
docs/tindie/full_in_battery.jpg

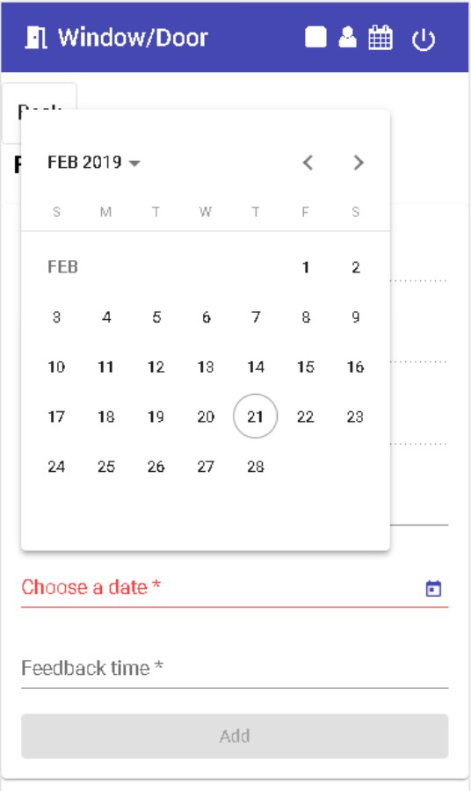
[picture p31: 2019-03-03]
docs/tindie/choose_date_action_was_taken.jpg

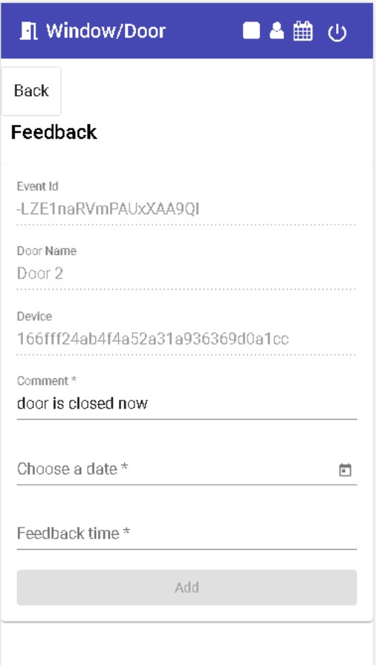
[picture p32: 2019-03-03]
docs/tindie/feedback_door_closed.jpg

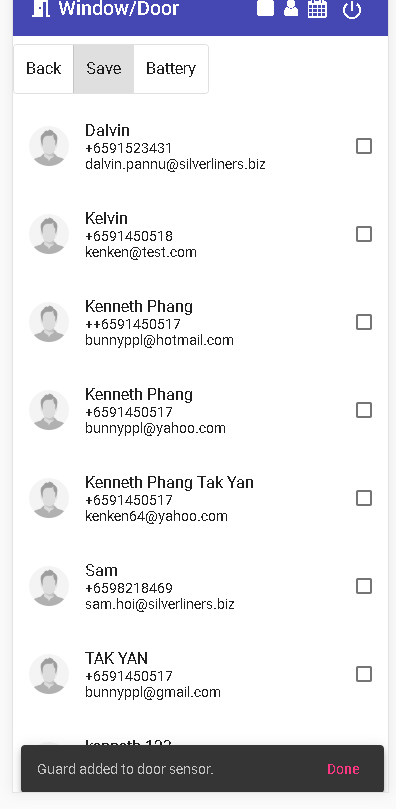
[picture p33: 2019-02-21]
docs/save_guard_door.png

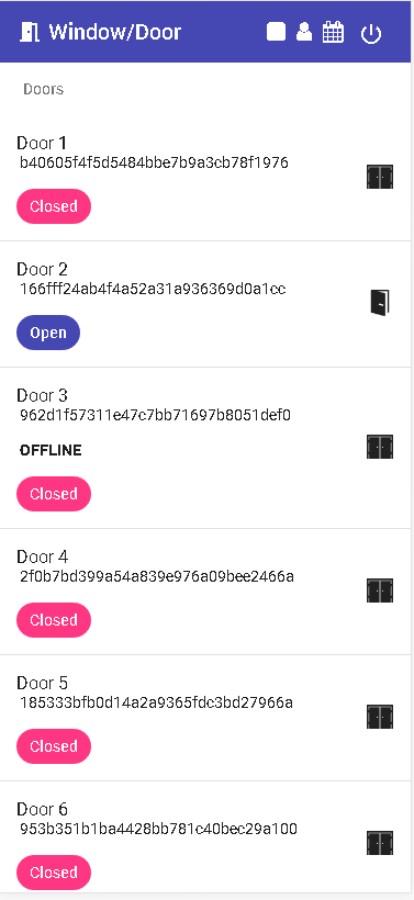
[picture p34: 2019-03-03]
docs/tindie/door_open.jpg

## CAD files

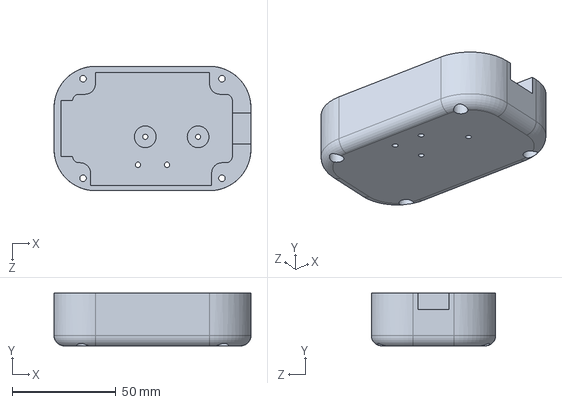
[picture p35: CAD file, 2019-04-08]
docs/bottom case.SLDPRT
95.0 x 25.5 x 60.0 mm

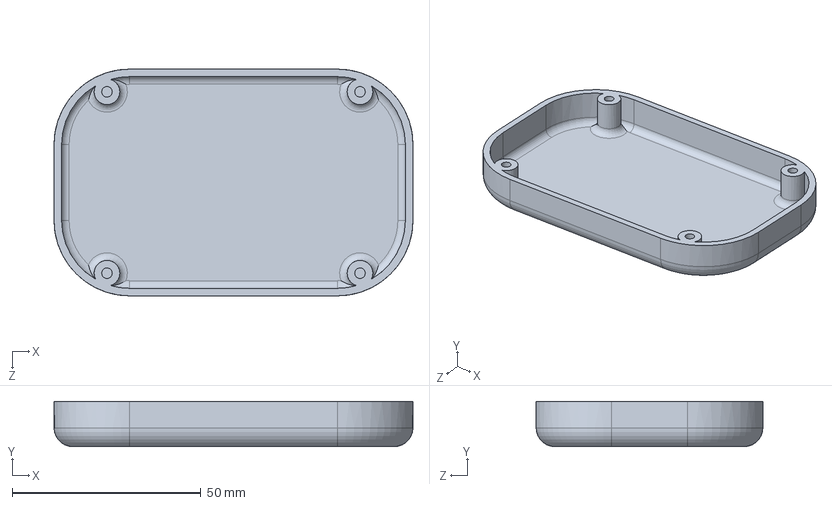
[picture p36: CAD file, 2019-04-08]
docs/case top.SLDPRT
95.0 x 12.0 x 60.0 mm

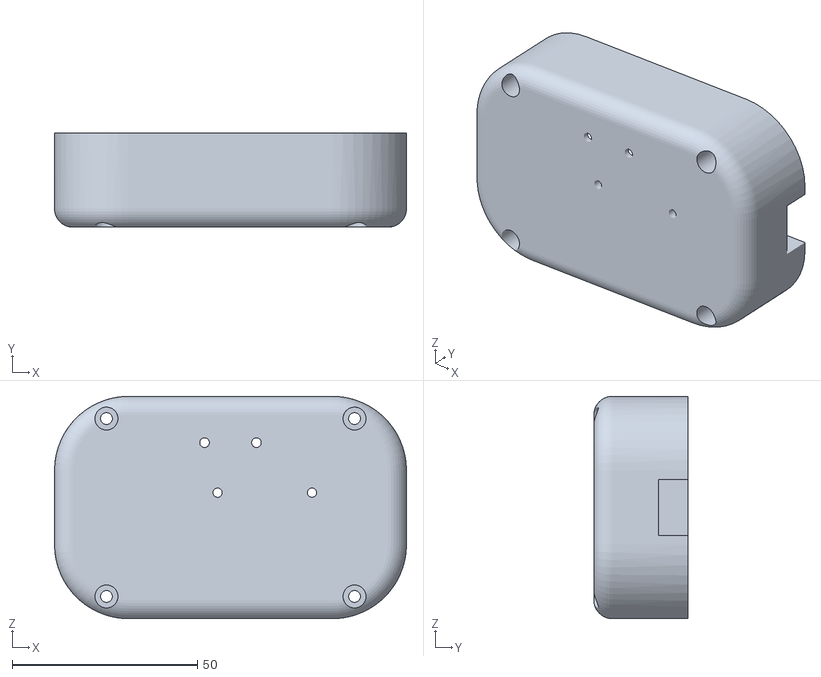
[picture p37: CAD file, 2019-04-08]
docs/case v2.STL
95.0 x 25.5 x 60.0

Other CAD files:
docs/case top.STL

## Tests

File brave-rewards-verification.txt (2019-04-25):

This is a Brave Rewards publisher verification file.

Domain: kennethphang.asia
Token: 7494b01965a9f60f8fc21ac621da497478accf858eb153be7b62adedd2a01510

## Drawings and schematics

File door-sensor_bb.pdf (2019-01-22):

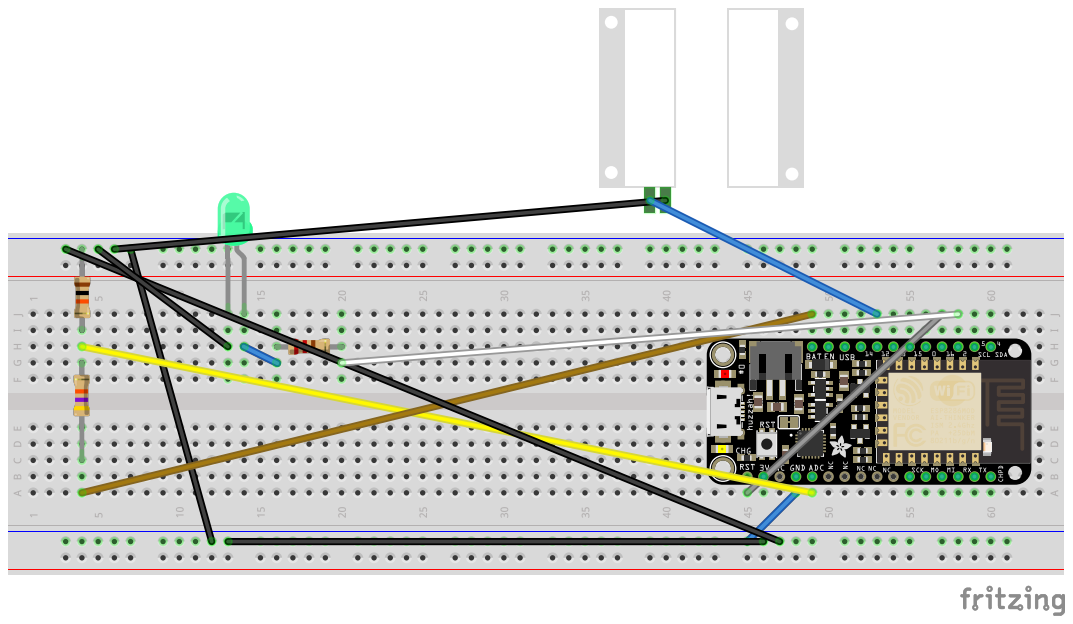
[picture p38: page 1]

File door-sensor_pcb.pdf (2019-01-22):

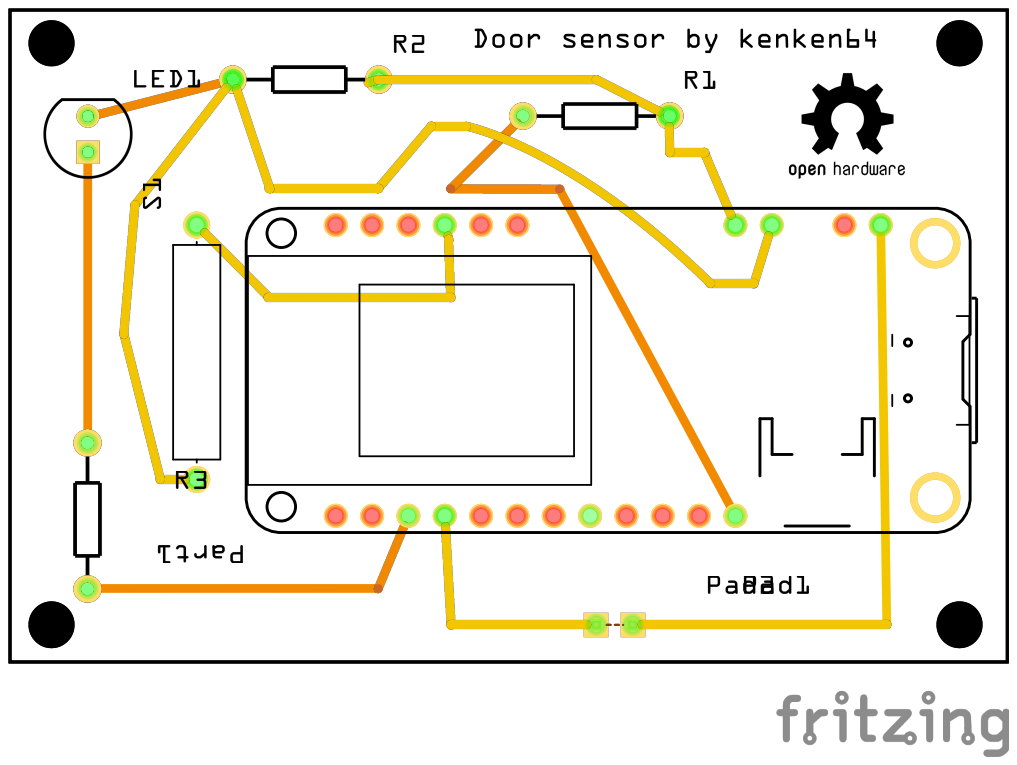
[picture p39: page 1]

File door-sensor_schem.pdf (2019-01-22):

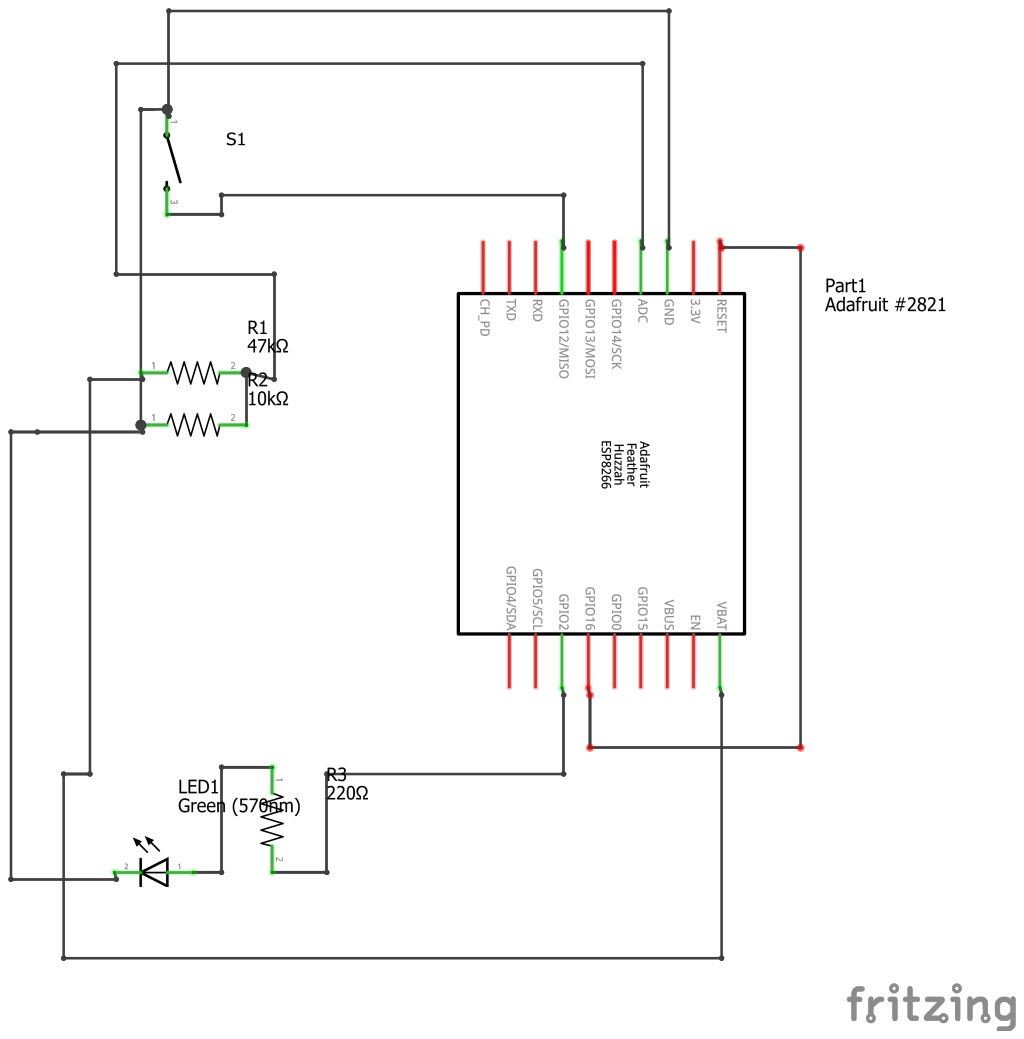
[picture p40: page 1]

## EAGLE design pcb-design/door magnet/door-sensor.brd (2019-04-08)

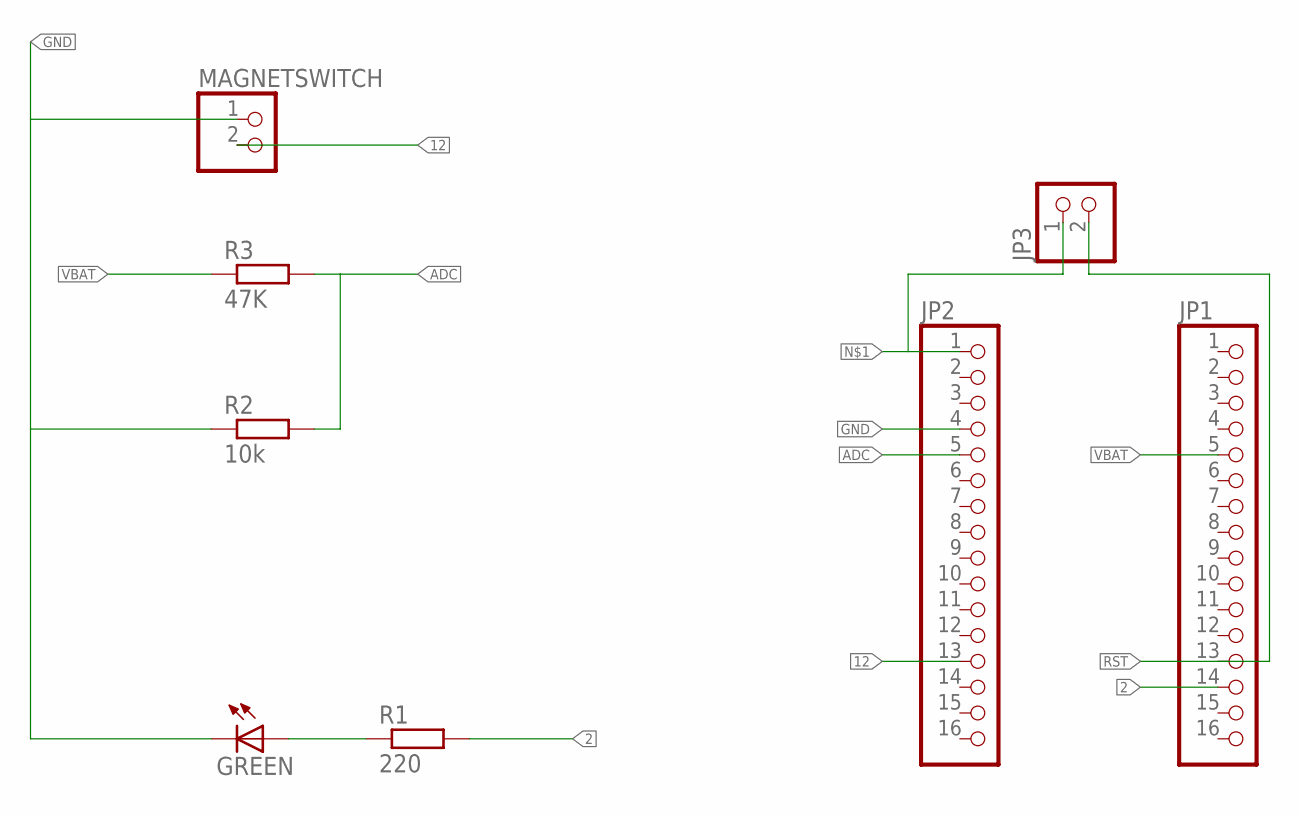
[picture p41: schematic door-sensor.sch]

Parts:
GREEN: LED_ELD260; LED_LD260
JP1, JP2: PINHD-1X16; 1X16
JP3: PINHD-1X2; 1X02
MAGNETSWITCH: PINHD-1X2; 1X02
R1: 220; 0204/7
R2: 10k; 0204/7
R3: 47K; 0204/7

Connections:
2: JP1.14, R1.2
12: JP2.13, MAGNETSWITCH.2
ADC: JP2.5, R2.2, R3.2
GND: GREEN.K (C), JP2.4, MAGNETSWITCH.1, R2.1
unnamed: JP2.1, JP3.1
unnamed: GREEN.A, R1.1
RST: JP1.13, JP3.2
VBAT: JP1.5, R3.1

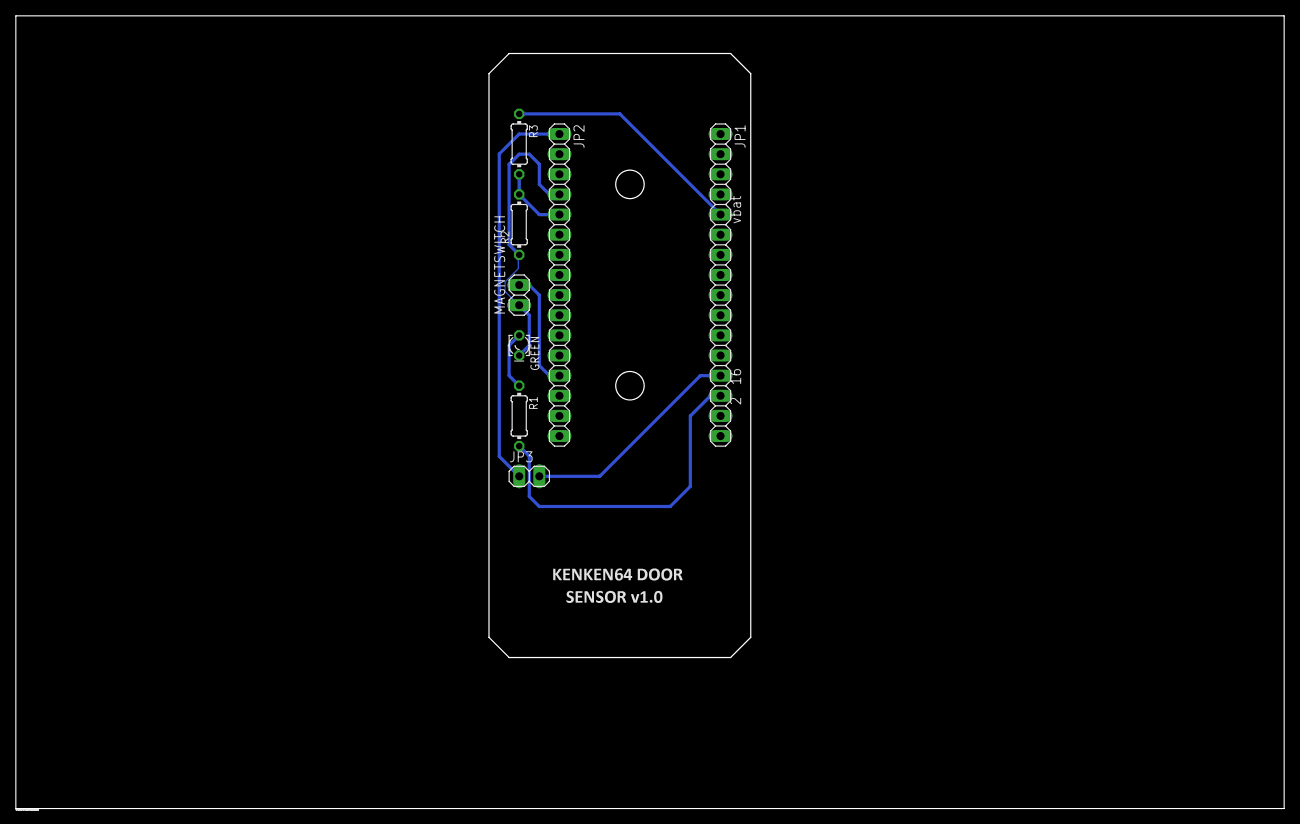
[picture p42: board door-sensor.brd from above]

Board: 2 copper layers, 160.0 x 100.0 mm, 8 parts (0 on the bottom side), 8 nets.

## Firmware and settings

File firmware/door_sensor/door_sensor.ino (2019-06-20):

#include <FS.h> 
#include "ESPBattery.h";
#define BLYNK_PRINT Serial
#include <ESP8266WiFi.h>
#include <BlynkSimpleEsp8266.h>
#include <ESP8266HTTPClient.h>
#include <ESP8266httpUpdate.h>

//needed for library
#include <DNSServer.h>
#include <ESP8266WebServer.h>
#include <WiFiManager.h>          //https://github.com/tzapu/WiFiManager

#include <ArduinoJson.h>   

// You should get Auth Token in the Blynk App.
// Go to the Project Settings (nut icon).
char blynk_token[33] = "b40605f4f5d5484bbe7b9a3cb78f1976";

//flag for saving data
bool shouldSaveConfig = false;

const int doorSensor = 12;
const int greenLED = 2;
// Time to sleep (in seconds):
const int sleepTimeS = 10;

BlynkTimer timer;
ESPBattery battery = ESPBattery();
const char* fwUrlBase = "https://ota-firmware.kennethphang.asia/firmware/";
const int FW_VERSION = 107;

//callback notifying us of the need to save config
void saveConfigCallback () {
  Serial.println("Should save config");
  shouldSaveConfig = true;
}

BLYNK_CONNECTED() {
  Blynk.syncAll();
}

BLYNK_WRITE(V0) //Button Widget is writing to pin V0
{
  int pinData = param.asInt();
  Serial.println("nothing to flash >> firmware " + pinData);
  if(pinData == 1){
    Serial.println("flash firmware...is 1");
    checkForUpdates();
    Blynk.virtualWrite(V4, FW_VERSION);
  }
}

void doorSensorWidget()
{
  int state = digitalRead(doorSensor);
  int batterPct  = battery.getPercentage();
  Serial.println(state);
  digitalWrite(greenLED, LOW);

  if (isnan(state) || isnan(state)) {
    Serial.println("Failed to read from door sensor!");
    return;
  }
  
  if (isnan(batterPct) || isnan(batterPct)) {
    Serial.println("Failed to read from battery pct!");
    return;
  }

  /*
  if(state == HIGH){
    Serial.println("Door Closed");
    Serial.print("Percentage: ");
    Serial.println(battery.getPercentage());
    Blynk.virtualWrite(V1, 0);
    Blynk.virtualWrite(V2, battery.getPercentage());
    Blynk.virtualWrite(V3, battery.getLevel());
    Blynk.virtualWrite(V4, FW_VERSION);
    Serial.println("ESP8266 in sleep mode");
    ESP.deepSleep(10e6, WAKE_RF_DEFAULT);
  }else {
    Serial.println("Door Open");
    Serial.print("Percentage: ");
    Serial.println(battery.getPercentage());
    analogWrite(greenLED,1023);
    Blynk.virtualWrite(V1, 1);
    Blynk.virtualWrite(V2, battery.getPercentage());
    Blynk.virtualWrite(V3, battery.getLevel());
    Blynk.virtualWrite(V4, FW_VERSION);
    delay(30);
  }*/
  
  
   if(state == HIGH){
    Serial.println("Door Open");
    Serial.print("Percentage: ");
    Serial.println(battery.getPercentage());
    analogWrite(greenLED,1023);
    Blynk.virtualWrite(V1, 1);
    Blynk.virtualWrite(V2, battery.getPercentage());
    Blynk.virtualWrite(V3, battery.getLevel());
    Blynk.virtualWrite(V4, FW_VERSION);
    delay(30);
  }else {
    Serial.println("Door Closed");
    Serial.print("Percentage: ");
    Serial.println(battery.getPercentage());
    Blynk.virtualWrite(V1, 0);
    Blynk.virtualWrite(V2, battery.getPercentage());
    Blynk.virtualWrite(V3, battery.getLevel());
    Serial.println("ESP8266 in sleep mode");
    Blynk.virtualWrite(V4, FW_VERSION);
    ESP.deepSleep(10e6, WAKE_RF_DEFAULT);
  }
}

void checkForUpdates() {
  String mac = getMAC();
  String fwURL = String( fwUrlBase );
  String fwVersionURL = fwURL;
  fwVersionURL.concat( blynk_token );

  Serial.println( "Checking for firmware updates." );
  Serial.print( "MAC address: " );
  Serial.println( mac );
  Serial.print( "Firmware version URL: " );
  fwVersionURL.concat( ".bin" );
  Serial.println( fwVersionURL );

  HTTPClient httpClient;
  
  httpClient.begin( fwVersionURL, "49 4A 1D 7E F2 CD 58 36 2D BE 59 A3 0B 92 74 5A 90 FE 21 4E" );
  int httpCode = httpClient.GET();
  Serial.println( httpCode );
  if( httpCode == 200 ) {
    Serial.println( "Preparing to update" );
    t_httpUpdate_return ret = ESPhttpUpdate.update( fwVersionURL );
    Serial.println( ret );
    switch(ret) {
      case HTTP_UPDATE_FAILED:
        Serial.printf("HTTP_UPDATE_FAILD Error (%d): %s", ESPhttpUpdate.getLastError(), ESPhttpUpdate.getLastErrorString().c_str());
        break;

      case HTTP_UPDATE_NO_UPDATES:
        Serial.println("HTTP_UPDATE_NO_UPDATES");
        break;
    }
  }
  else {
    Serial.print( "Firmware version check failed, got HTTP response code " );
    Serial.println( httpCode );
  }
  httpClient.end();
}


String getMAC()
{
  uint8_t mac[6];
  char result[14];
  snprintf( result, sizeof( result ), "%02x%02x%02x%02x%02x%02x", mac[ 0 ], mac[ 1 ], mac[ 2 ], mac[ 3 ], mac[ 4 ], mac[ 5 ] );
  return String( result );
}

void setup() {
  Serial.begin(9600);
  Serial.println();
  
  // enable this for testing
  //SPIFFS.format();
  
  Serial.println("mounting FS...");
  if (SPIFFS.begin()) {
    Serial.println("mounted file system");
    if (SPIFFS.exists("/config.json")) {
      //file exists, reading and loading
      Serial.println("reading config file");
      File configFile = SPIFFS.open("/config.json", "r");
      if (configFile) {
        Serial.println("opened config file");
        size_t size = configFile.size();
        // Allocate a buffer to store contents of the file.
        std::unique_ptr<char[]> buf(new char[size]);

        configFile.readBytes(buf.get(), size);
        DynamicJsonBuffer jsonBuffer;
        JsonObject& json = jsonBuffer.parseObject(buf.get());
        json.printTo(Serial);
        if (json.success()) {
          Serial.println("\nparsed json");

          strcpy(blynk_token, json["blynk_token"]);
        } else {
          Serial.println("failed to load json config");
        }
      }
    }
  } else {
    Serial.println("failed to mount FS");
  }
  //end read
  Serial.println(blynk_token);

  
  //WiFiManager
  //Local intialization. Once its business is done, there is no need to keep it around
  WiFiManager wifiManager;
  // enable this for testing
  //wifiManager.resetSettings();
  wifiManager.setSaveConfigCallback(saveConfigCallback);
  //set config save notify callback
  WiFiManagerParameter custom_blynk_token("blynk", "blynk token", blynk_token, 34);
  //add all your parameters here
  wifiManager.addParameter(&custom_blynk_token);

  //fetches ssid and pass and tries to connect
  //if it does not connect it starts an access point with the specified name
  //here  "AutoConnectAP"
  //and goes into a blocking loop awaiting configuration
  if (!wifiManager.autoConnect("AutoAPDoorSensor", "password1234")) {
    Serial.println("failed to connect and hit timeout");
    delay(3000);
    //reset and try again, or maybe put it to deep sleep
    ESP.reset();
    delay(5000);
  }

  //read updated parameters
  strcpy(blynk_token, custom_blynk_token.getValue());

  //save the custom parameters to FS
  if (shouldSaveConfig) {
    Serial.println("saving config");
    DynamicJsonBuffer jsonBuffer;
    JsonObject& json = jsonBuffer.createObject();
    json["blynk_token"] = blynk_token;

    File configFile = SPIFFS.open("/config.json", "w");
    if (!configFile) {
      Serial.println("failed to open config file for writing");
    }

    json.prettyPrintTo(Serial);
    json.printTo(configFile);
    configFile.close();
    //end save
  }
  while (WiFi.status() != WL_CONNECTED) {
    Serial.println("Connecting to WIFI ...");
  }
  Serial.println("local ip");
  Serial.println(WiFi.localIP());
  Serial.println(WiFi.gatewayIP());
  Serial.println(WiFi.subnetMask());
  
  pinMode(doorSensor,INPUT_PULLUP);
  pinMode(greenLED, OUTPUT);
  Serial.println(blynk_token);
  Blynk.config(blynk_token);
  Blynk.connect();
  Serial.println("BLYNK Connected ? " + Blynk.connected());
  battery.setLevelChangedHandler(stateHandler);
  Serial.println("\n\nLevel charging Handler");
  stateHandler(battery);
  timer.setInterval(1000L, doorSensorWidget);
}

void loop() {
  battery.loop();
  Blynk.run();
  timer.run();
  static unsigned long last = millis();
  if (millis() - last > 5000) {
      last = millis();
      Serial.printf("[MAIN] Free heap: %d bytes\n", ESP.getFreeHeap());
  }
}

void stateHandler(ESPBattery& b) {
  int state = b.getState();
  int level = b.getLevel();
  Serial.print("\nCurrent state: ");
  Serial.println(b.stateToString(state));
  Serial.print("Current level: ");
  Serial.println(b.getLevel());
  Serial.print("Percentage: ");
  Serial.println(b.getPercentage());
  Serial.print("Voltage: ");
  Serial.println(b.getVoltage());
}

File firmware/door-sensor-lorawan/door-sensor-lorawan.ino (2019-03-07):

#include <lmic.h>
#include <hal/hal.h>
#include <SPI.h>

// LoRaWAN NwkSKey, network session key
// This is the default Semtech key, which is used by the prototype TTN
// network initially.
static const PROGMEM u1_t NWKSKEY[16] = { 0xE3, 0x8F, 0xFF, 0xFD, 0xA3, 0xB8, 0xD2, 0xF7, 0xAA, 0x76, 0x3F, 0x6E, 0x6A, 0xB9, 0xC1, 0xC7 };

// LoRaWAN AppSKey, application session key
// This is the default Semtech key, which is used by the prototype TTN
// network initially.
static const u1_t PROGMEM APPSKEY[16] = { 0x07, 0x9E, 0x35, 0xE4, 0x2B, 0xDD, 0xAD, 0xE9, 0x3A, 0x25, 0xA5, 0x6D, 0x52, 0x39, 0x96, 0xF1 };

// LoRaWAN end-device address (DevAddr)
// See http://thethingsnetwork.org/wiki/AddressSpace
static const u4_t DEVADDR = 0x26062701; // <-- Change this address for every node!

// These callbacks are only used in over-the-air activation, so they are
// left empty here (we cannot leave them out completely unless
// DISABLE_JOIN is set in config.h, otherwise the linker will complain).
void os_getArtEui (u1_t* buf) { }
void os_getDevEui (u1_t* buf) { }
void os_getDevKey (u1_t* buf) { }

static uint8_t mydata[] = "Hello, world! Kenneth";
static osjob_t sendjob;

// Schedule TX every this many seconds (might become longer due to duty
// cycle limitations).
const unsigned TX_INTERVAL = 60;

// Pin mapping
const lmic_pinmap lmic_pins = {
    .nss = 10,
    .rxtx = LMIC_UNUSED_PIN,
    .rst = 9,
    .dio = {2, 6, 7},
};

void onEvent (ev_t ev) {
    Serial.print(os_getTime());
    Serial.print(": ");
    switch(ev) {
        case EV_SCAN_TIMEOUT:
            Serial.println(F("EV_SCAN_TIMEOUT"));
            break;
        case EV_BEACON_FOUND:
            Serial.println(F("EV_BEACON_FOUND"));
            break;
        case EV_BEACON_MISSED:
            Serial.println(F("EV_BEACON_MISSED"));
            break;
        case EV_BEACON_TRACKED:
            Serial.println(F("EV_BEACON_TRACKED"));
            break;
        case EV_JOINING:
            Serial.println(F("EV_JOINING"));
            break;
        case EV_JOINED:
            Serial.println(F("EV_JOINED"));
            break;
        case EV_RFU1:
            Serial.println(F("EV_RFU1"));
            break;
        case EV_JOIN_FAILED:
            Serial.println(F("EV_JOIN_FAILED"));
            break;
        case EV_REJOIN_FAILED:
            Serial.println(F("EV_REJOIN_FAILED"));
            break;
            break;
        case EV_TXCOMPLETE:
            Serial.println(F("EV_TXCOMPLETE (includes waiting for RX windows)"));
            if(LMIC.dataLen) {
                // data received in rx slot after tx
                Serial.print(F("Data Received: "));
                Serial.write(LMIC.frame+LMIC.dataBeg, LMIC.dataLen);
                Serial.println();
            }
            // Schedule next transmission
            os_setTimedCallback(&sendjob, os_getTime()+sec2osticks(TX_INTERVAL), do_send);
            break;
        case EV_LOST_TSYNC:
            Serial.println(F("EV_LOST_TSYNC"));
            break;
        case EV_RESET:
            Serial.println(F("EV_RESET"));
            break;
        case EV_RXCOMPLETE:
            // data received in ping slot
            Serial.println(F("EV_RXCOMPLETE"));
            break;
        case EV_LINK_DEAD:
            Serial.println(F("EV_LINK_DEAD"));
            break;
        case EV_LINK_ALIVE:
            Serial.println(F("EV_LINK_ALIVE"));
            break;
         default:
            Serial.println(F("Unknown event"));
            break;
    }
}

void do_send(osjob_t* j){
    // Check if there is not a current TX/RX job running
    if (LMIC.opmode & OP_TXRXPEND) {
        Serial.println(F("OP_TXRXPEND, not sending"));
    } else {
        // Prepare upstream data transmission at the next possible time.
        LMIC_setTxData2(1, mydata, sizeof(mydata)-1, 0);
        Serial.println(F("Packet queued"));
        Serial.println("Packet queued");
        Serial.print("LMIC.freq:");
        Serial.println(LMIC.freq);
        Serial.println("");
        Serial.println("");
        Serial.println("Receive data:");
    }
    // Next TX is scheduled after TX_COMPLETE event.
}

void setup() {
    Serial.begin(115200);
    Serial.println(F("Starting"));

    #ifdef VCC_ENABLE
    // For Pinoccio Scout boards
    pinMode(VCC_ENABLE, OUTPUT);
    digitalWrite(VCC_ENABLE, HIGH);
    delay(1000);
    #endif

    // LMIC init
    os_init();
    // Reset the MAC state. Session and pending data transfers will be discarded.
    LMIC_reset();

    // Set static session parameters. Instead of dynamically establishing a session
    // by joining the network, precomputed session parameters are be provided.
    #ifdef PROGMEM
    // On AVR, these values are stored in flash and only copied to RAM
    // once. Copy them to a temporary buffer here, LMIC_setSession will
    // copy them into a buffer of its own again.
    uint8_t appskey[sizeof(APPSKEY)];
    uint8_t nwkskey[sizeof(NWKSKEY)];
    memcpy_P(appskey, APPSKEY, sizeof(APPSKEY));
    memcpy_P(nwkskey, NWKSKEY, sizeof(NWKSKEY));
    LMIC_setSession (0x1, DEVADDR, nwkskey, appskey);
    #else
    // If not running an AVR with PROGMEM, just use the arrays directly 
    LMIC_setSession (0x1, DEVADDR, NWKSKEY, APPSKEY);
    #endif
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

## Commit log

2019-01-06 fix the pin
2019-01-13 fix the battery issue
    [door_sensor.ino]
2019-01-22 send pcb to manufacturing
    [door-sensor.fzz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]
2019-01-29 added battery indicator
    [door-events_export_1548749686384.xlsx]
2019-01-29 fix battery bugs
2019-02-12 added filter bottom sheet
2019-02-13 completed the badges on the button
2019-02-13 added filter
2019-02-21 fix the current time on add feedback
2019-03-09 fix when rechargeable not available
    [door_sensor_esp32.ino]
2019-03-09 fix battery issues with some devices
2019-03-17 fix a bug
    [door-events_export_1552702869963.xlsx]
2019-03-25 fix send sms and email bugs
    [door_sensor_esp32.ino]
2019-04-08 new stuff
    [bottom case.SLDPRT, case top.SLDPRT, case top.STL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]
2019-04-08 added eagle schematic
    [door-events_export_1548749686384.xlsx, door-events_export_1552702869963.xlsx, door-events_export_1554052046772.xlsx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]
2019-04-09 fix battery check
2019-04-26 clean up
    [door-sensor.brd, door-sensor.sch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]
